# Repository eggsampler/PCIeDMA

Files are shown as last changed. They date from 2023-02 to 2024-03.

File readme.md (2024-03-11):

# PCIeDMA

Open source Artix-7 FPGA designed to be used with [PCILeech](https://github.com/ufrisk/pcileech/).

For schematic/layout/assembly/pcb diagrams, please see the [outputs](outputs/) folder.

## Overview

Initial design was based on a combination of the [LambdaConcept PCIe Screamer Squirrel](https://shop.lambdaconcept.com/home/50-screamer-pcie-squirrel.html) and the [Enigma-X1 LeetDMA](https://enigma-x1.com/store/product/23-leetdma-incl-custom-fw/).

PCIexpress layout is based on [lucanastasio/PCIexpress-KiCad](https://github.com/lucanastasio/PCIexpress-KiCad) PCIexpress_x4_low.

Initially will try to keep the board as a 6-layer PCB using the [JLC3313 6-Layer Impedance Control Stackup](https://cart.jlcpcb.com/impedance), layer stackup plan would be Signal/Ground/Power/Power/Ground/Signal, with the outside signal layers also having a ground pour. PCIe and USB3 SS traces would be impedance matched (and length matched as necessary) on top and bottom layers as coplanar waveguides for each pair.

There are two on-board USB-C ports, one for JTAG debugging/programming of the FPGA/flash, the other as a usb superspeed link for DMA access. The board is also designed such that it can be powered and programmed/tested from the JTAG USB connector, without needing to be plugged into a PCIe slot.

## Progress 

From a high level perspective, the board is largely complete. It does, however, need to be checked before first batch ordered. The following is a rough list of what needs to be reviewed, and any input is welcome from knowledgeable parties.

* [ ] Schematic Review
  * [ ] Part Selection
  * [ ] BOM Check
  * [ ] Connectivity

* [ ] PCB Review
  * [ ] Placement
  * [ ] Footprints
  * [ ] Routing
  * [ ] Impedance

Once board is finalised, the software side needs to be started integrating with PCILeech. Specifically, [PCILeech FPGA](https://github.com/ufrisk/pcileech-fpga)

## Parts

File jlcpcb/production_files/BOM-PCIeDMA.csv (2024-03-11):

Comment | Designator | Footprint | LCSC
EA3059 | U12 | QFN-24-1EP_4x4mm_P0.5mm_EP2.6x2.6mm | C111586
1k | R24,R25,R26,R27,R29,R30,R31,R32,R33,R34,R35,R36,R37,R38,R39,R40,R64,R66,R67,R71,R9 | R_0402_1005Metric | C11702
USB_C_Receptacle | J4 | USB_C_Receptacle_Molex_105450-0101 | C134092
110k | R43 | R_0402_1005Metric | C138065
15 | R1,R4 | R_0402_1005Metric | C144049
100u | C72 | C_1206_3216Metric | C15008
AO3401A | Q2,Q3,Q5 | SOT-23 | C15127
XC7A35T-FGG484 | U8 | Xilinx_FGG484 | C1521727
0.1u | C101,C119,C120,C121,C122,C124,C126,C127,C128,C14,C21,C24,C26,C29,C31,C32,C33,C34,C35,C36,C37,C38,C39,C40,C41,C42,C44,C45,C48,C49,C88,C89,C9,C91 | C_0402_1005Metric | C1525
220p | C106,C107,C108,C109 | C_0402_1005Metric | C1530
22n | C114,C115,C92,C97 | C_0402_1005Metric | C1532
FT601Q | U7 | QFN-76-1EP_9x9mm_P0.4mm_EP5.81x6.31mm | C1550513
20p | C27,C28 | C_0402_1005Metric | C1554
22p | C93,C98 | C_0402_1005Metric | C1555
HD3SS3220 | U6 | HD3SS3220 | C165155
USB_C_Receptacle_USB2.0 | J2 | USB_C_Receptacle_HRO_TYPE-C-31-M-12 | C165948
0.22u | C1,C10,C11,C12,C13,C15,C16,C17,C18,C2,C3,C4,C5,C6,C7,C8 | C_0402_1005Metric | C16772
TBD | FB1,FB2,FB3 | L_0805_2012Metric | C16903
SW_SPDT | SW5 | ST-0-102-C03-N003-RS | C1788489
4.7u | C123,C125,C130,C131,C43,C46,C47,C51,C52,C59,C60,C66,C67,C75,C76,C78,C79 | C_0603_1608Metric | C19666
MMBT3904 | Q4 | SOT-23 | C20526
ACT | D1,D2,D3,D4,D5,D6 | LED_0603_1608Metric | C2290
USER1 | SW1,SW2,SW3,SW4 | SW_SPST_B3U-1000P | C231329
900k | R19 | R_0805_2012Metric | C247071
100 | R10,R11,R12,R14,R15,R28,R68 | R_0402_1005Metric | C25076
100k | R45,R46,R47,R48,R51,R52,R54,R56,R57,R59,R60,R61,R62,R65 | R_0402_1005Metric | C25741
10k | R21,R22,R41,R42,R50,R63 | R_0402_1005Metric | C25744
50k | R49,R53,R55 | R_0402_1005Metric | C25755
15k | R44 | R_0402_1005Metric | C25756
200k | R20,R58 | R_0402_1005Metric | C25764
4.7k | R69,R70 | R_0402_1005Metric | C25900
5.1k | R13,R16,R17,R18,R2,R3,R5,R6,R7,R8 | R_0402_1005Metric | C25905
8MHz | Y1 | Crystal_SMD_3225-4Pin_3.2x2.5mm | C2682775
47n | C116,C118 | C_0402_1005Metric | C272875
MT47H128M8SH-25E IT_M | U13 | FBGA-60_L10.0-W8.0-P0.80-TL_MICRON_MT47HXXX | C2839094
Conn_01x10 | J3 | PinHeader_1x10_P1.27mm_Vertical | C2938404
100MHz | X1,X2 | Crystal_SMD_3225-4Pin_3.2x2.5mm | C2962756
30MHz | Y2 | Crystal_SMD_3225-4Pin_3.2x2.5mm | C362343
A6H-4101 | SW6 | SW_DIP_SPSTx04_Slide_Omron_A6H-4101_W6.15mm_P1.27mm | C397291
1.6k | R23 | R_0402_1005Metric | C413085
22u | C100,C110,C111,C112,C113,C19,C22,C90,C94,C95,C96,C99 | C_0805_2012Metric | C45783
0.47u | C132,C133,C134,C135,C53,C54,C55,C56,C61,C62,C63,C64,C68,C69,C70,C71,C77,C80,C81,C82,C83,C84,C85,C86,C87 | C_0402_1005Metric | C47339
CH347T | U2 | TSSOP-20_4.4x6.5mm_P0.65mm | C5122332
1.5u | L3,L4,L5,L6 | L_Abracon_ASPI-3012S | C528005
TPD4EUSB30 | U1,U3,U4,U5 | USON-10_2.5x1.0mm_P0.5mm | C558427
IS25WP256D-xL | U9 | WSON-8-1EP_8x6mm_P1.27mm_EP3.4x4.3mm | C77819
4.7uH | L1,L2 | L_Vishay_IHLP-2020 | C844990
2N7002 | Q1 | SOT-23 | C8545
MT2492 | U10,U11 | SOT-23-6 | C89358
47u | C129,C50,C57,C58,C65,C73,C74 | C_1206_3216Metric | C96123
10u | C102,C103,C104,C105,C117,C20,C23,C25,C30 | C_0603_1608Metric | C96446

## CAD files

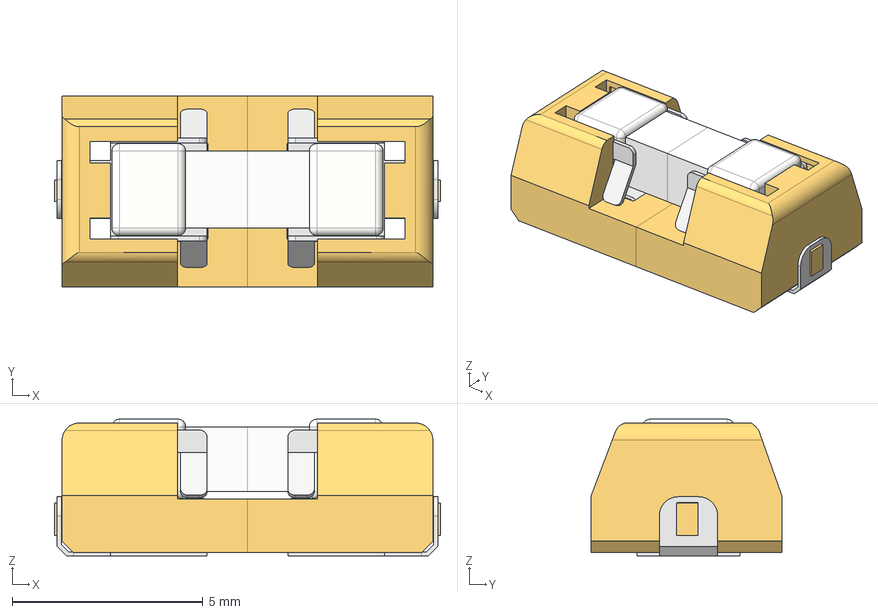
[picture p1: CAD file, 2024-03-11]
3d/Littelfuse 0154.500DRT without value v1.step
10.1 x 5.00 x 3.59 mm
Komponente1
Komponente2
Komponente3
Komponente4

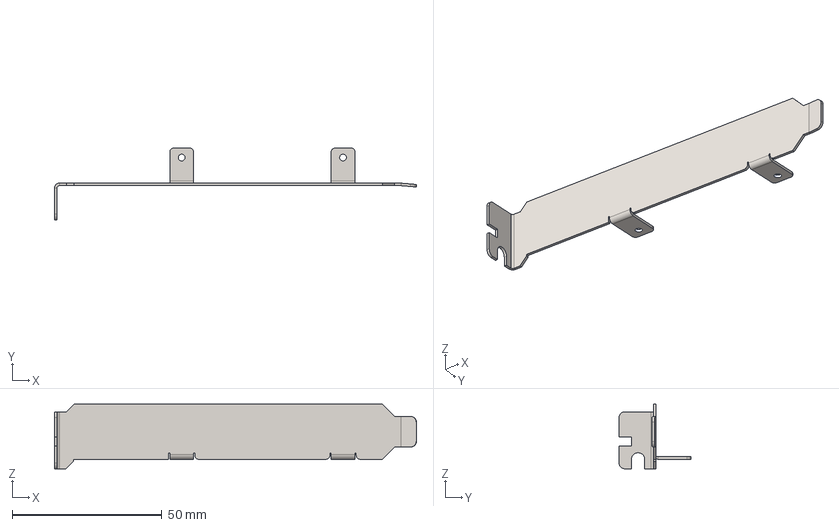
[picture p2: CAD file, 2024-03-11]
3d/PCIexpress_bracket_adapter.step
120.9 x 24.0 x 21.6 mm

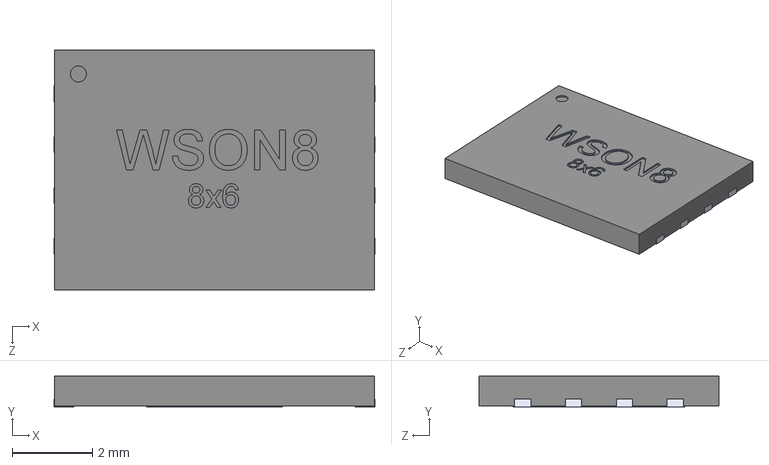
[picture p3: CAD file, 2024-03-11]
3d/WSON8-8x6.STEP
8.02 x 0.77 x 6.00 mm

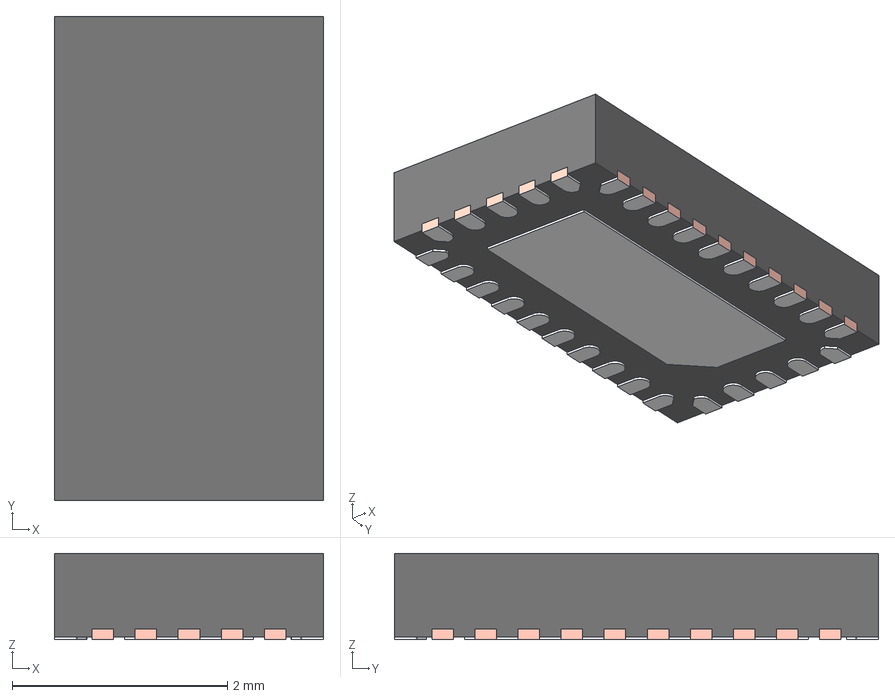
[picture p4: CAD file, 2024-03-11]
3d/RNH0030A.stp
2.50 x 4.50 x 0.8 mm
BODY-QFN
FRAME-RNH0030A
PIN1-ID

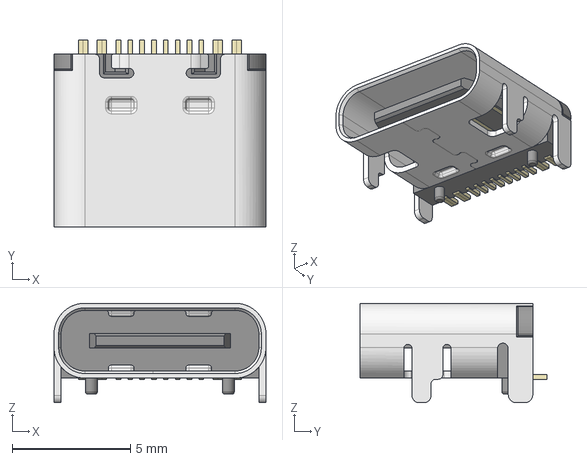
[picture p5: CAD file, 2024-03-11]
3d/HRO_TYPE-C-31-M-12.step
8.95 x 7.90 x 4.20 mm

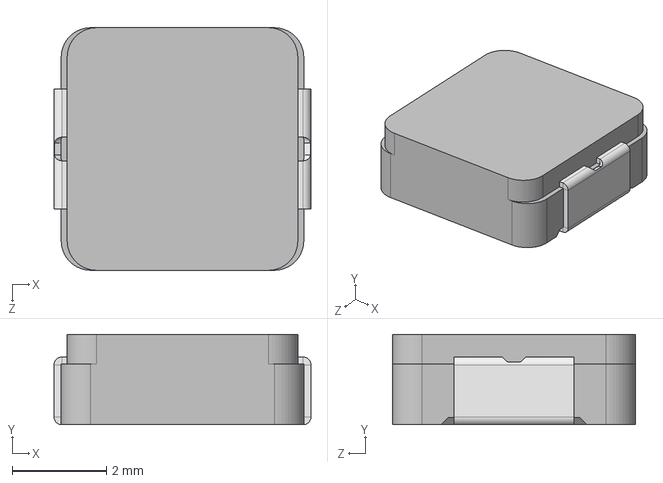
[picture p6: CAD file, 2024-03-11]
3d/IHLP2020BZ.STEP
5.45 x 1.92 x 5.15 mm

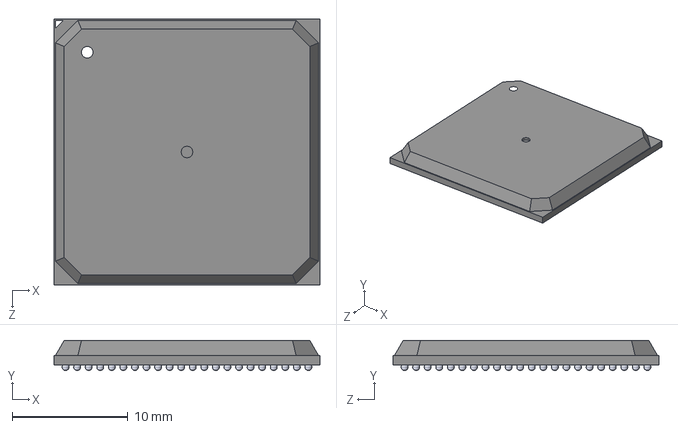
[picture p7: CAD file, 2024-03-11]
3d/XC7A35T-3FGG484E.STEP
23.0 x 2.60 x 23.0 mm

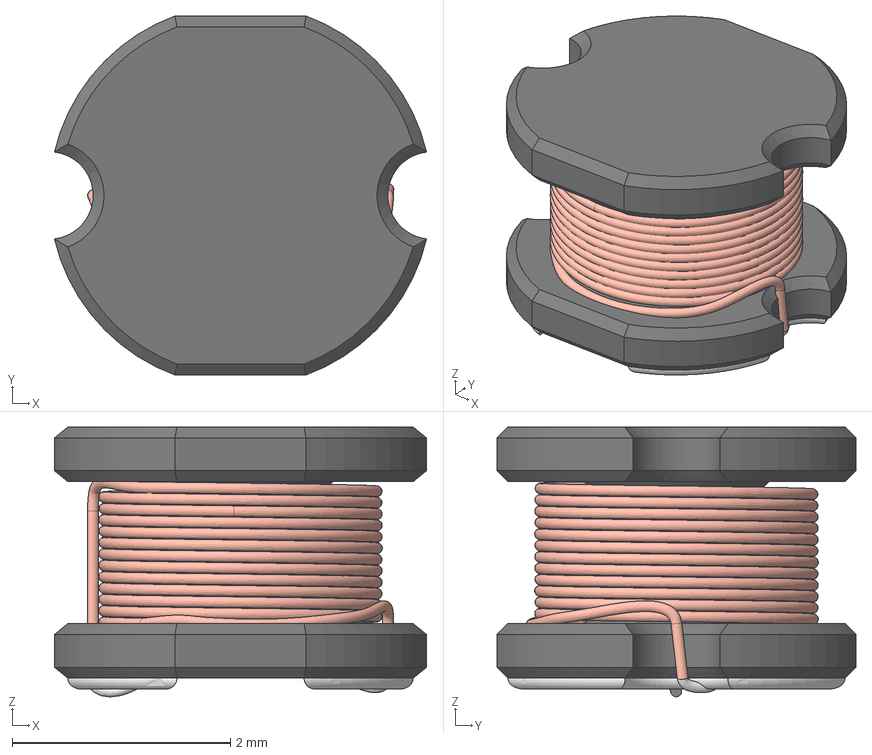
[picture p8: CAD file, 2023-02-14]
3d/Inductor_CD32.STEP
3.41 x 3.29 x 2.47 mm

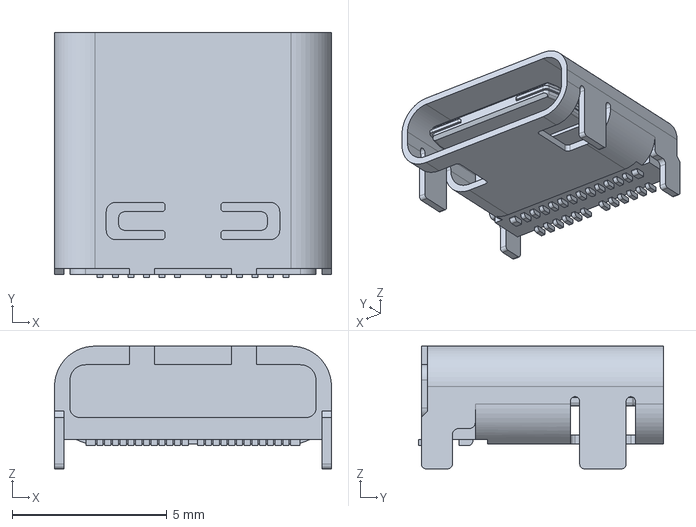
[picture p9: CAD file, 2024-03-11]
3d/1054500101.stp
8.94 x 7.90 x 3.96 mm

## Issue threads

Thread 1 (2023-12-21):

please reply

cht870422, 2023-12-21:
Has your engineering project undergone sample testing?

eggsampler, 2023-12-21:
No. Project needs to be reviewed and have some changes made before production.

cht870422, 2023-12-22:
Less appearance, less drilling, less resistance welding,

cht870422, 2023-12-23:
You can conduct a final error check on your project and submit an update. I can help you make samples and conduct testing If you have any needs, I can also send you a sample card by mail I live in China and manufacturing this hardware is very easy and affordable

eggsampler, 2023-12-24:
I might have time to look at this over the Christmas break - what do you want to use it for>

cht870422, 2023-12-24:
Thank you for taking the time to reply and be willing to conduct the final inspection for this project. I have a suggestion that this PCB can be changed from 8 layers to 4 layers. If you use a 4-layer circuit board, the production cost will be reduced. You can leave your mailing address or contact information for online communication. I suggest using WeChat because it supports translation, or you recommend a communication software

Inzilkin, 2024-01-08:
@eggsampler, Hi. I see that the development process has started, any info on plans or timelines?

eggsampler, 2024-01-14:
No solid plans or timelines, unless you have FPGA design experience.

GRRENY, 2024-01-15:
> 感谢您抽出宝贵时间回复并愿意对本项目进行最终检查。我有一个建议，这个PCB可以从8层改成4层。如果使用4层电路板，生产成本会降低。您可以留下您的邮寄地址或联系信息以进行在线交流。我建议使用微信，因为它支持翻译，或者您推荐使用通信软件

Hello, I also live in China. May I ask which platform is the cheapest to produce samples?

eggsampler, 2024-01-15:
I have no idea if this will even work yet, needs review.

GRRENY, 2024-01-18:
Hello, thank you for the open source of the project. Have you finished reviewing these project materials? If you have reviewed it and it is correct, I am ready to produce a sample of the project. It is recommended that you leave your contact information, I have some questions I hope you can help me solve, thank you very much.

GRRENY, 2024-01-23:
Can you add your contact details? Hope to communicate with you further

eggsampler, 2024-01-23:
No communication required, needs to be reviewed by someone with fpga design experience.

Closed 2024-01-23.

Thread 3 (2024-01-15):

request

GRRENY, 2024-01-15:
Hello, can you share the production materials of other DMA equipment with me? It must be like PCIe Squirrel or Leet DMA, Captain DMA. Thank you very much and look forward to hearing from you。

eggsampler, 2024-01-15:
I have no idea what other cards use.

Closed 2024-01-15.

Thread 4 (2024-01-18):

Ask for help

GRRENY, 2024-01-18:
Hello, thank you for the open source of the project. Have you finished reviewing these project materials? If you have reviewed it and it is correct, I am ready to produce a sample of the project. It is recommended that you leave your contact information, I have some questions I hope you can help me solve, thank you very much.

GRRENY, 2024-01-20:
Once you have reviewed the project materials, I will produce a sample and mail it to you immediately.

Closed 2024-01-23.

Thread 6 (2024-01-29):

Amazing work. Part information

Rvnxxx, 2024-01-29:
Hay if at any point you are not too busy finishing DMA board. would you be able to put a list together and if/possible set of links to the chips/parts needed for the DMA board to be assembled in order for it to work? again amazing work <3.

eggsampler, 2024-01-30:
The BOM and placement files are in the output folder.

I do not recommend ordering until more work is done

Closed 2024-01-30.

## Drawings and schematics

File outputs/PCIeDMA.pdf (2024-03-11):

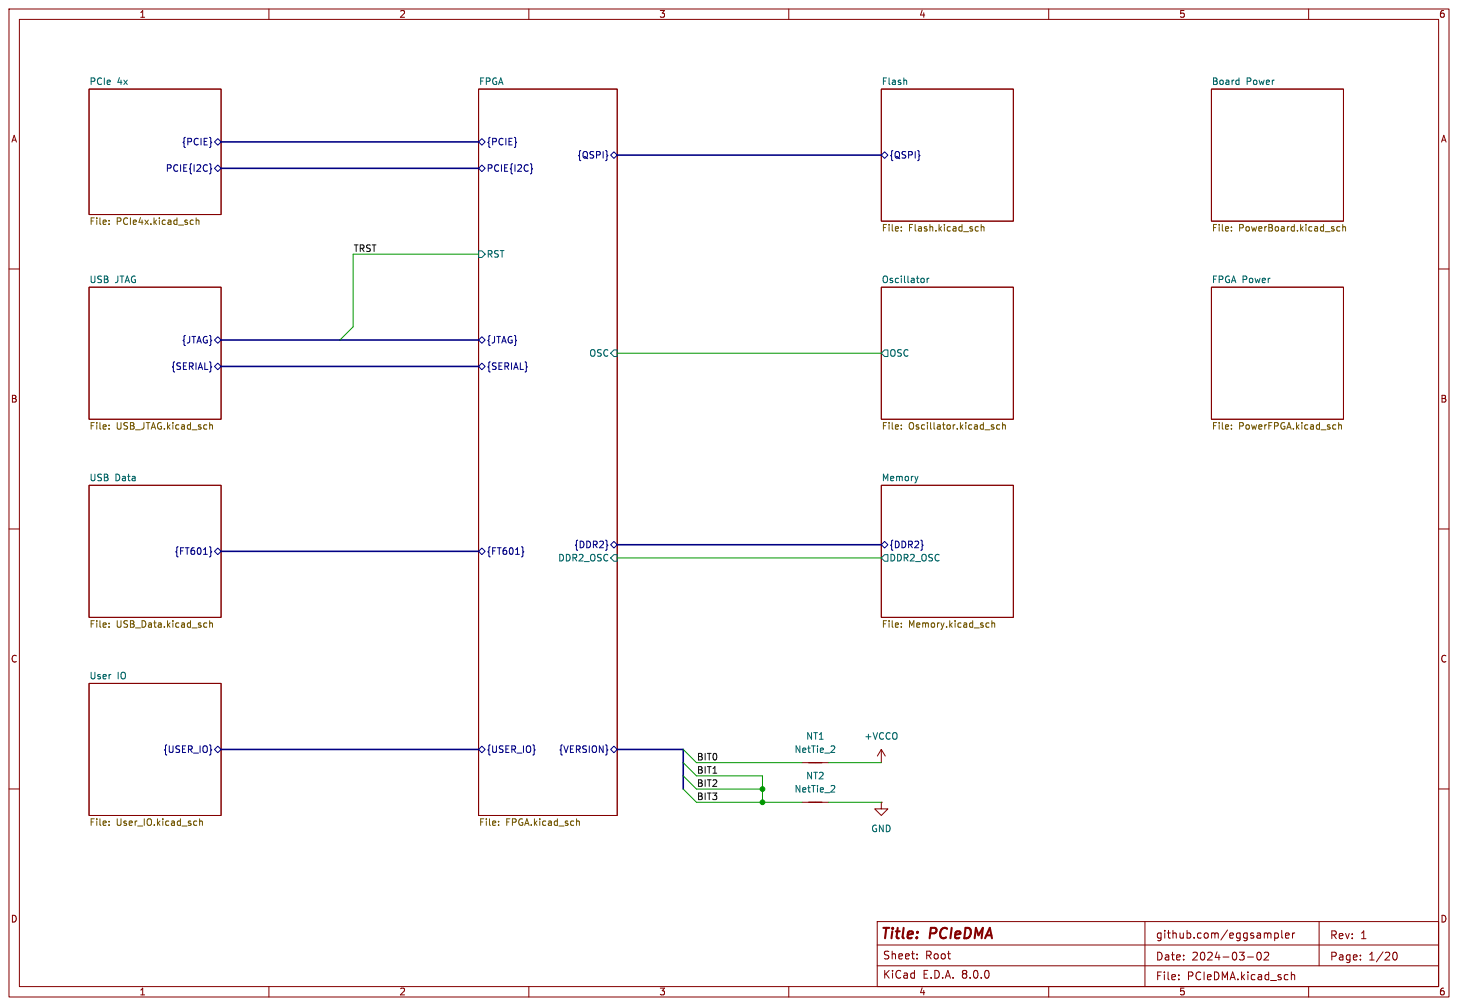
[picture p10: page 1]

{QSPI} Flash File: Flash.kicad_sch OSC Oscillator File: Oscillator.kicad_sch RST

Board Power File: PowerBoard.kicad_sch +VCCO

FPGA Power File: PowerFPGA.kicad_sch

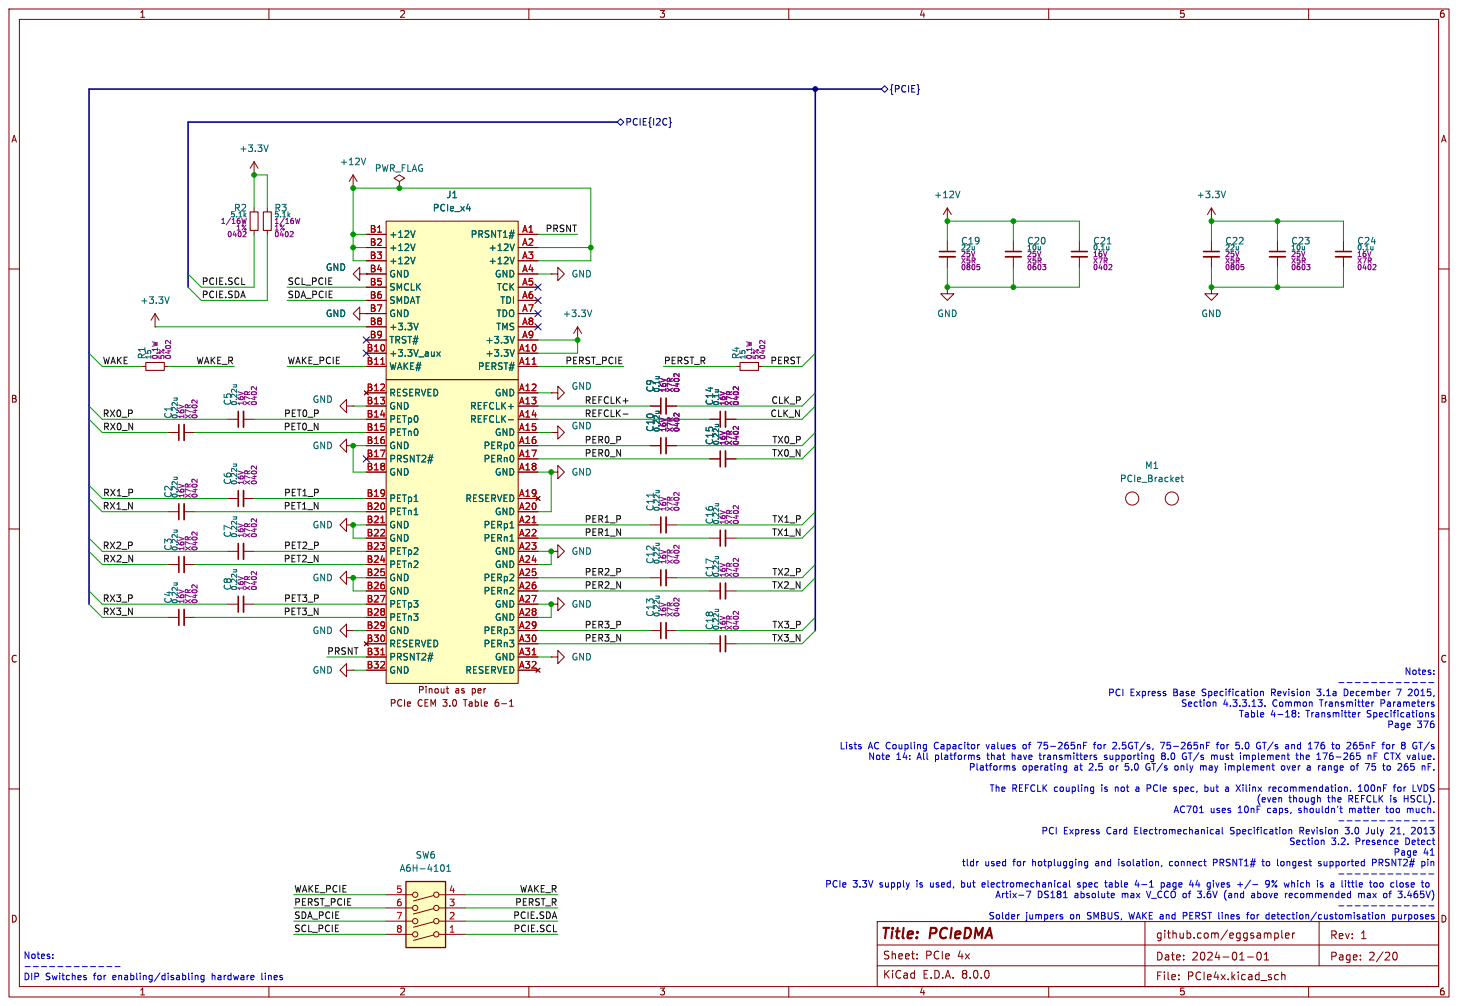
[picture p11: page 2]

PCIE.SCL PCIE.SDA

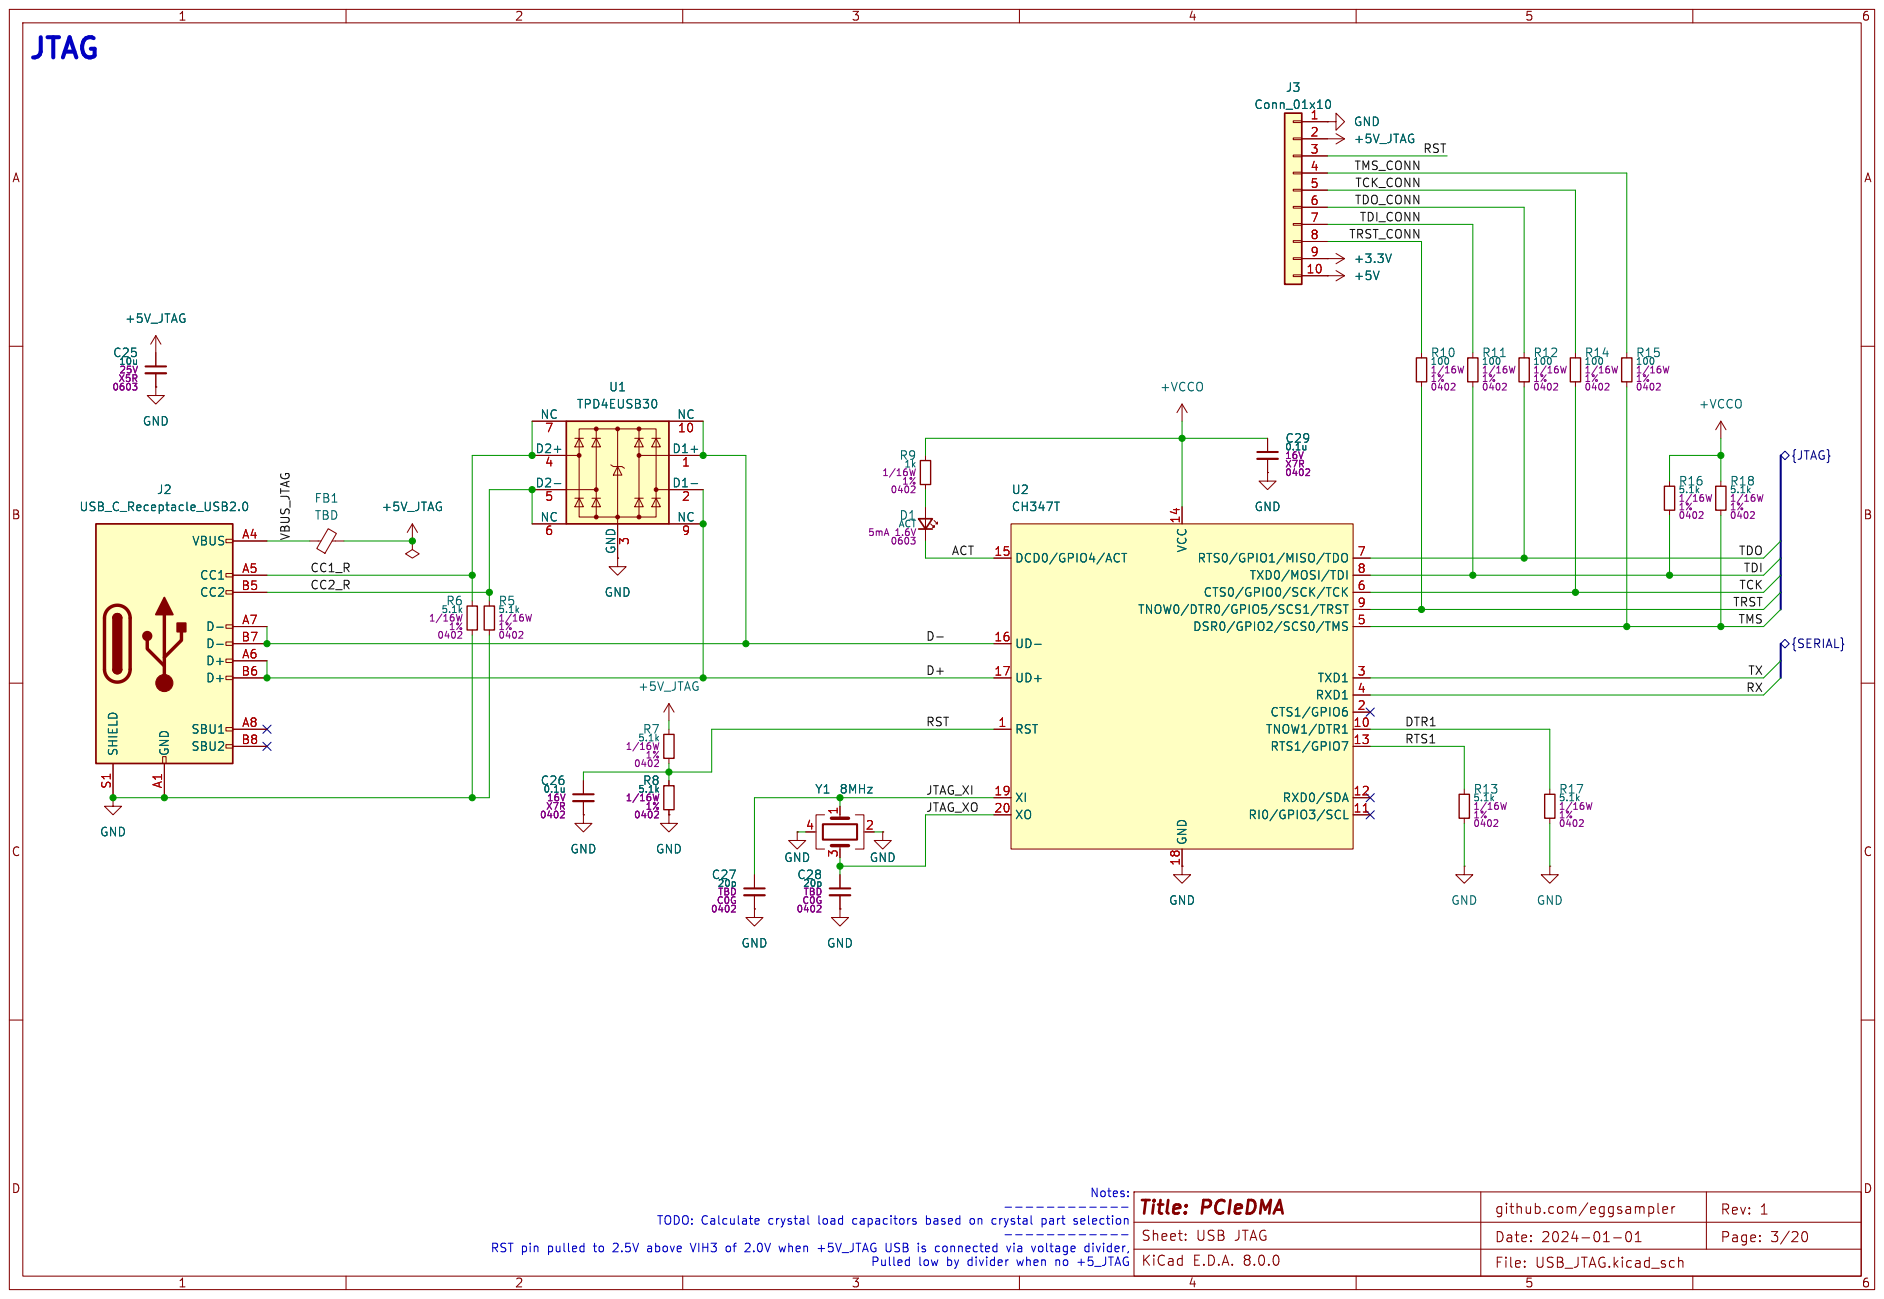
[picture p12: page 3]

github.com/eggsampler GND

File: USB_JTAG.kicad_sch Sheet: USB JTAG

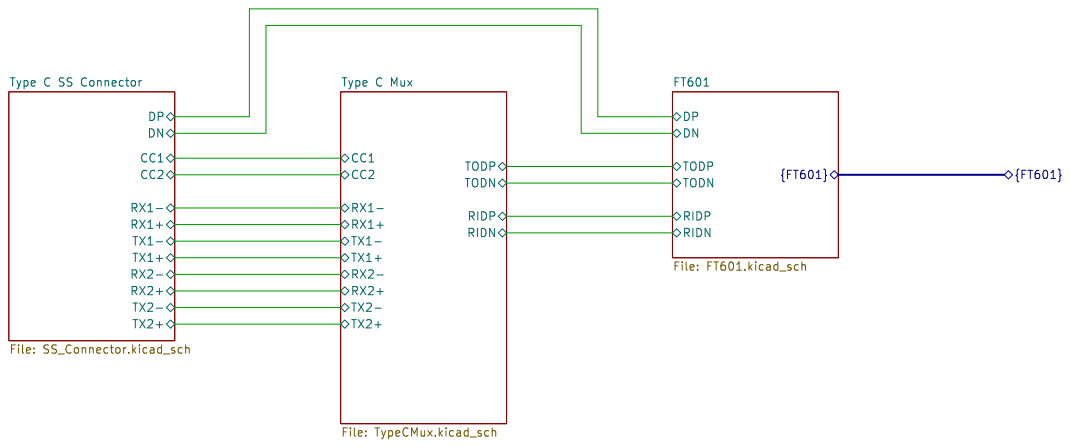
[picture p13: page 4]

TX1+ RX1+ TX1- RX2- TX2- RX2+ RX1- TX2+ CC2 CC1 Type C Mux File: TypeCMux.kicad_sch

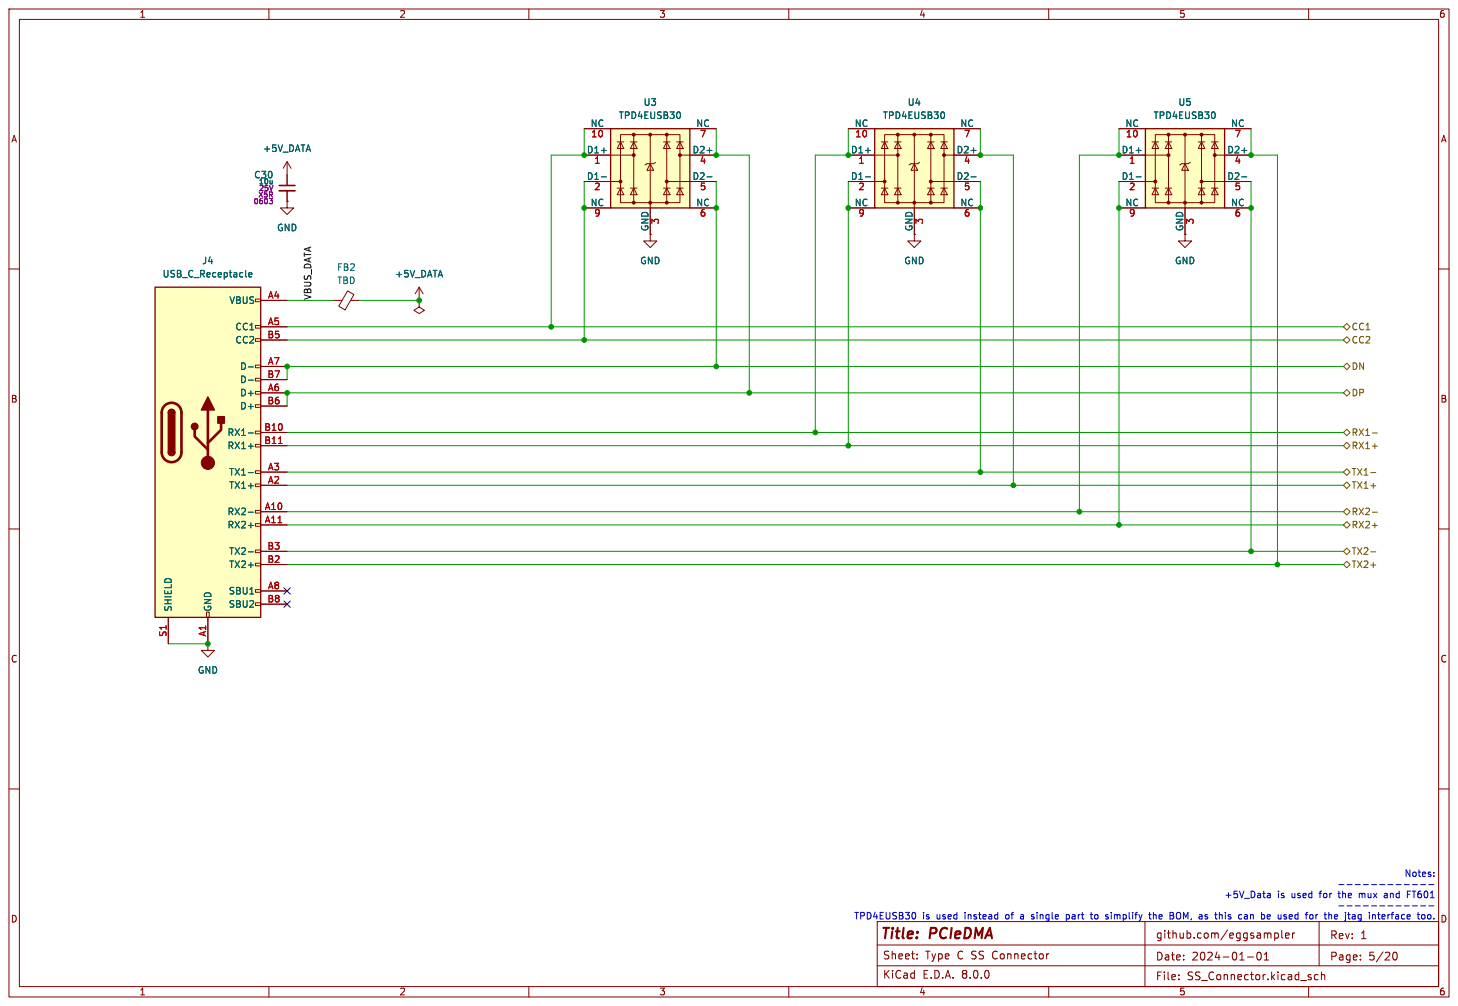
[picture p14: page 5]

Notes: ------------ +5V_Data is used for the mux and FT601

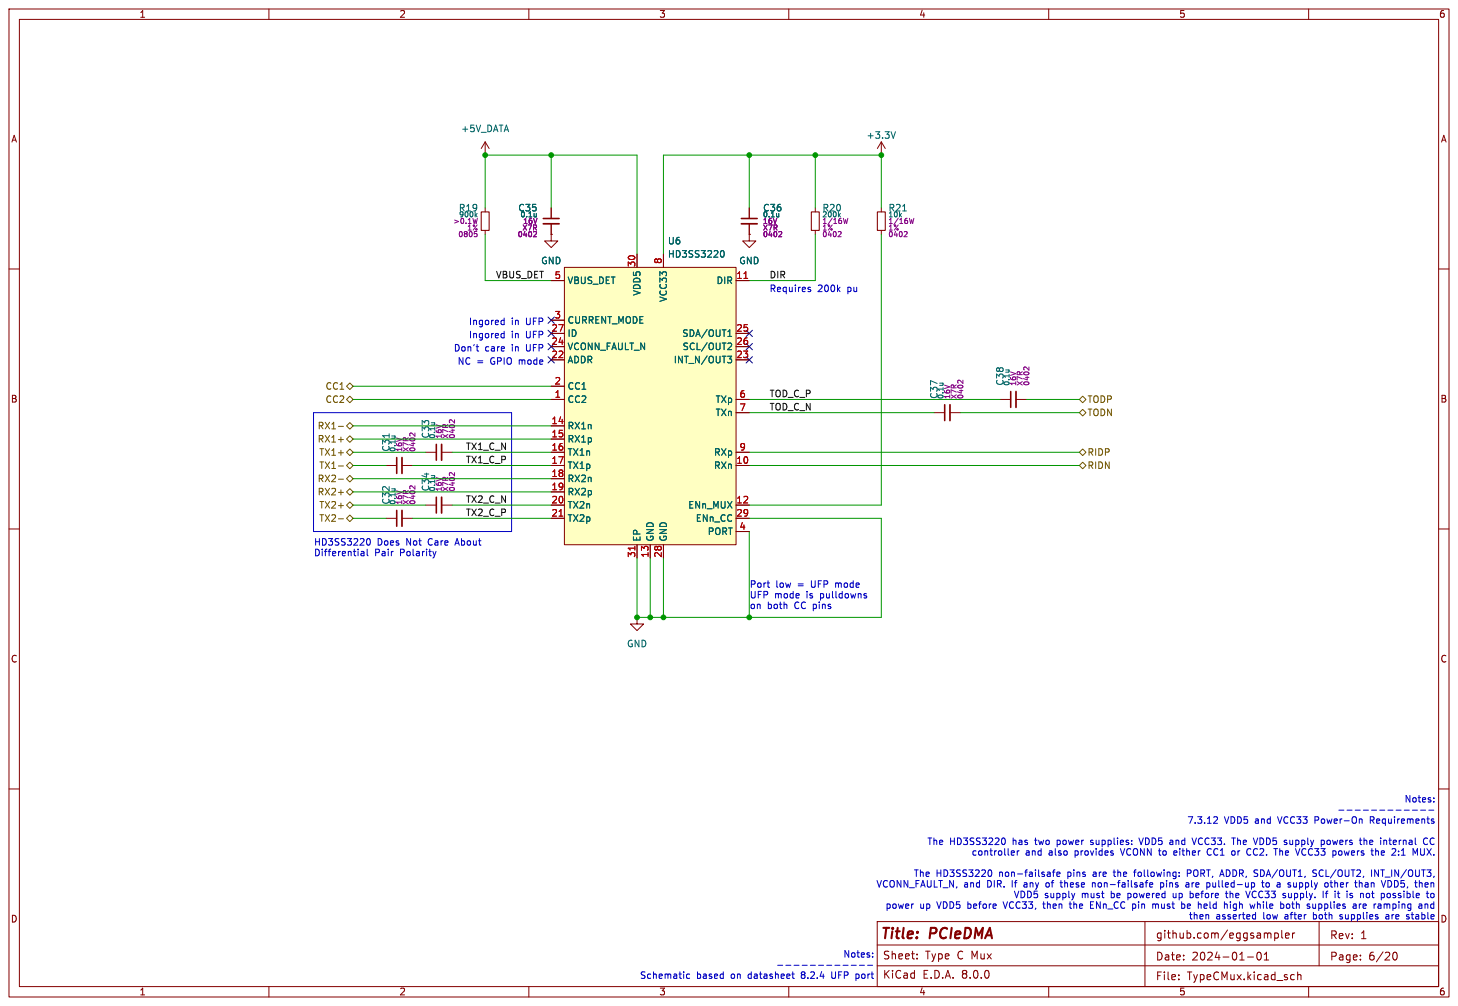
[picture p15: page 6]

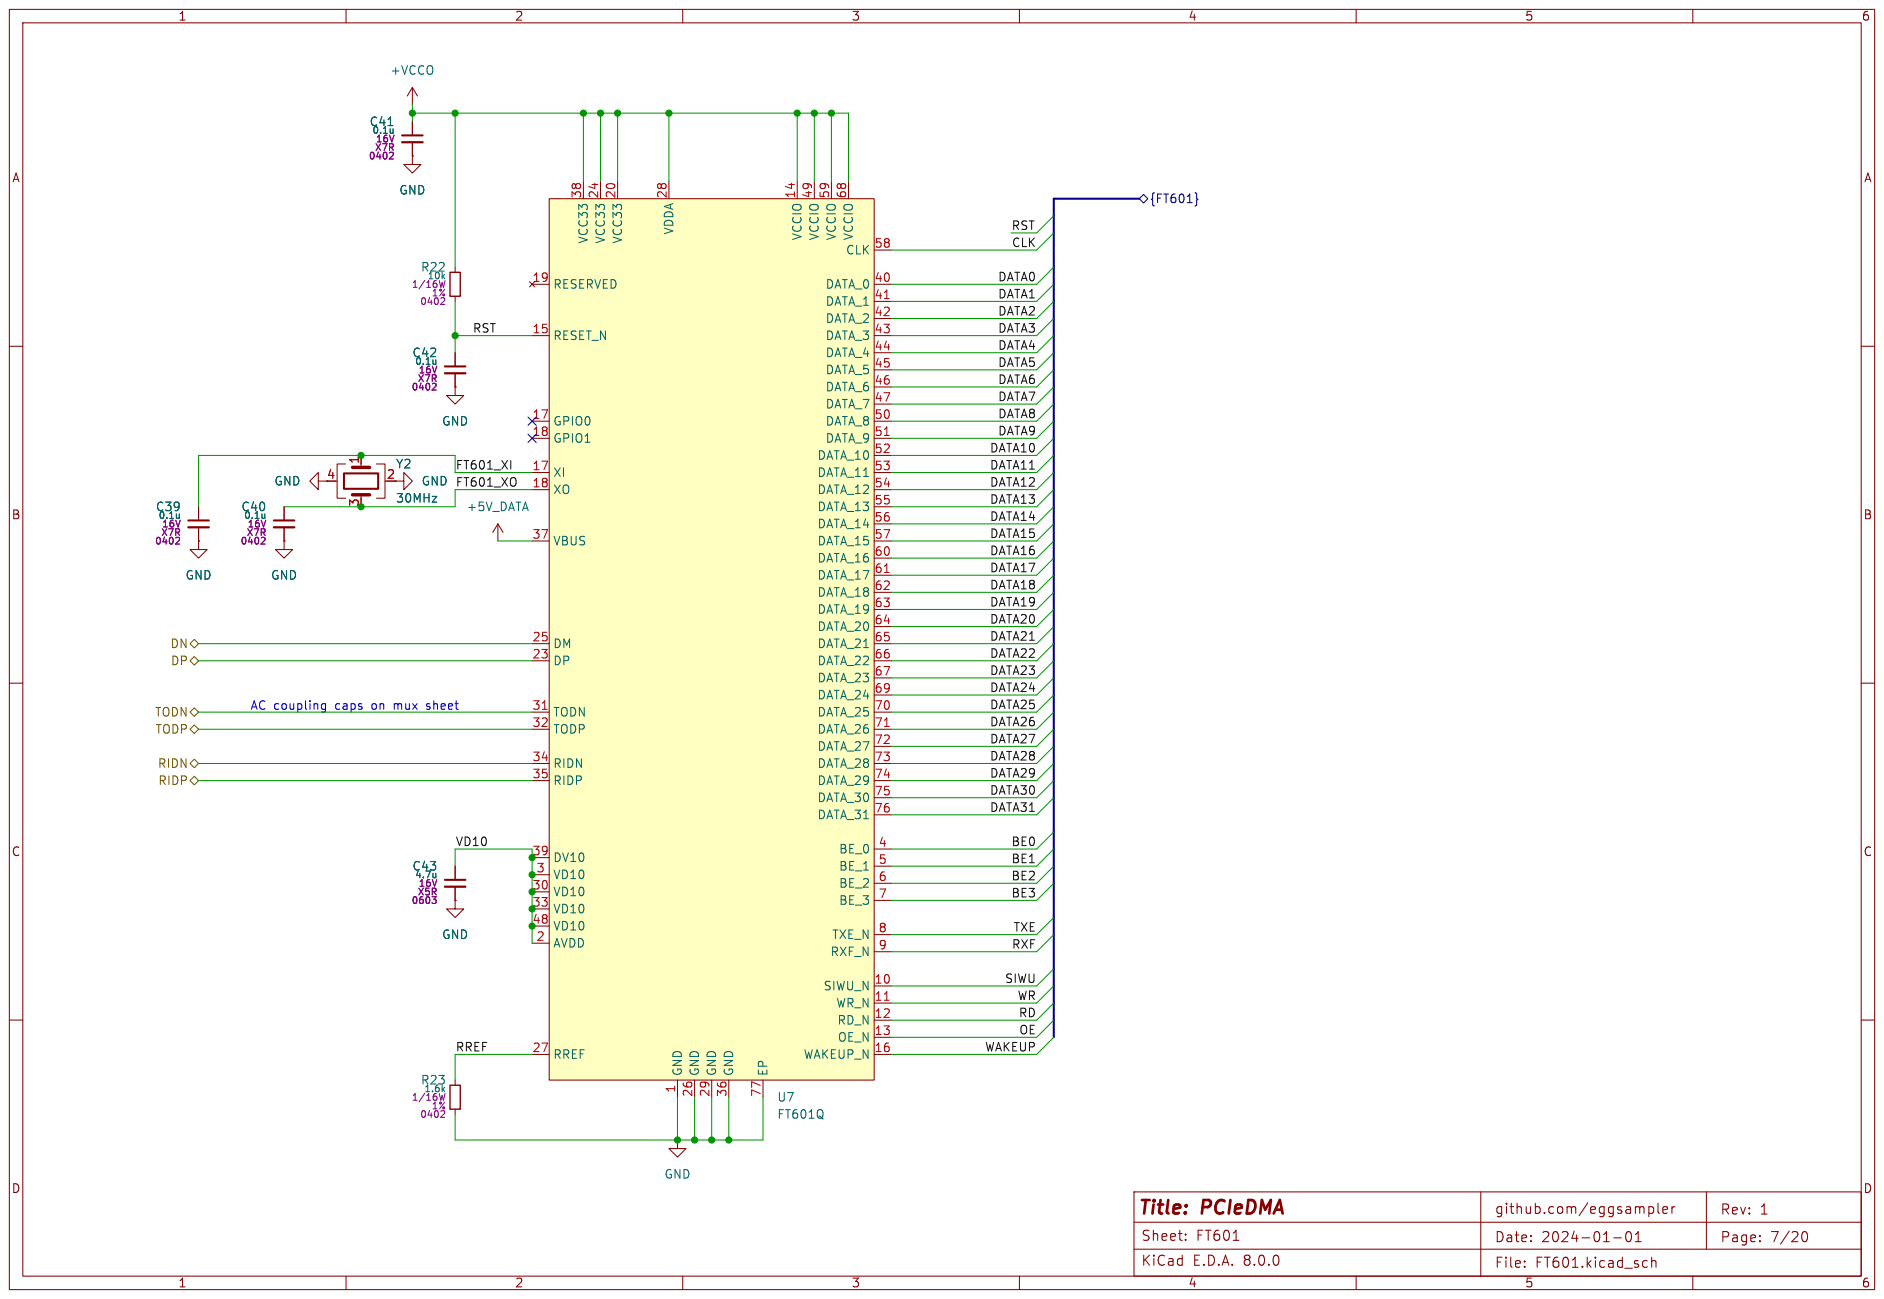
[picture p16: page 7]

github.com/eggsampler GND

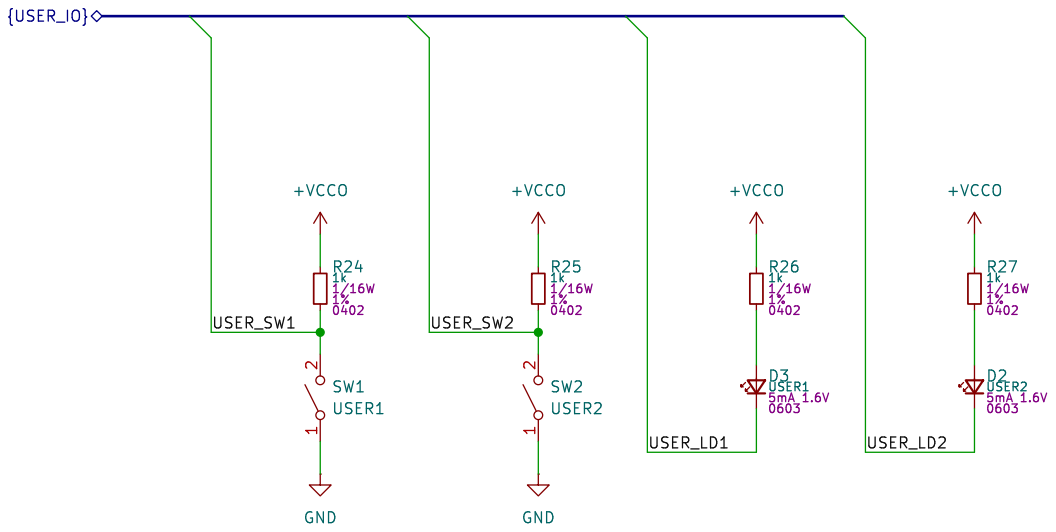
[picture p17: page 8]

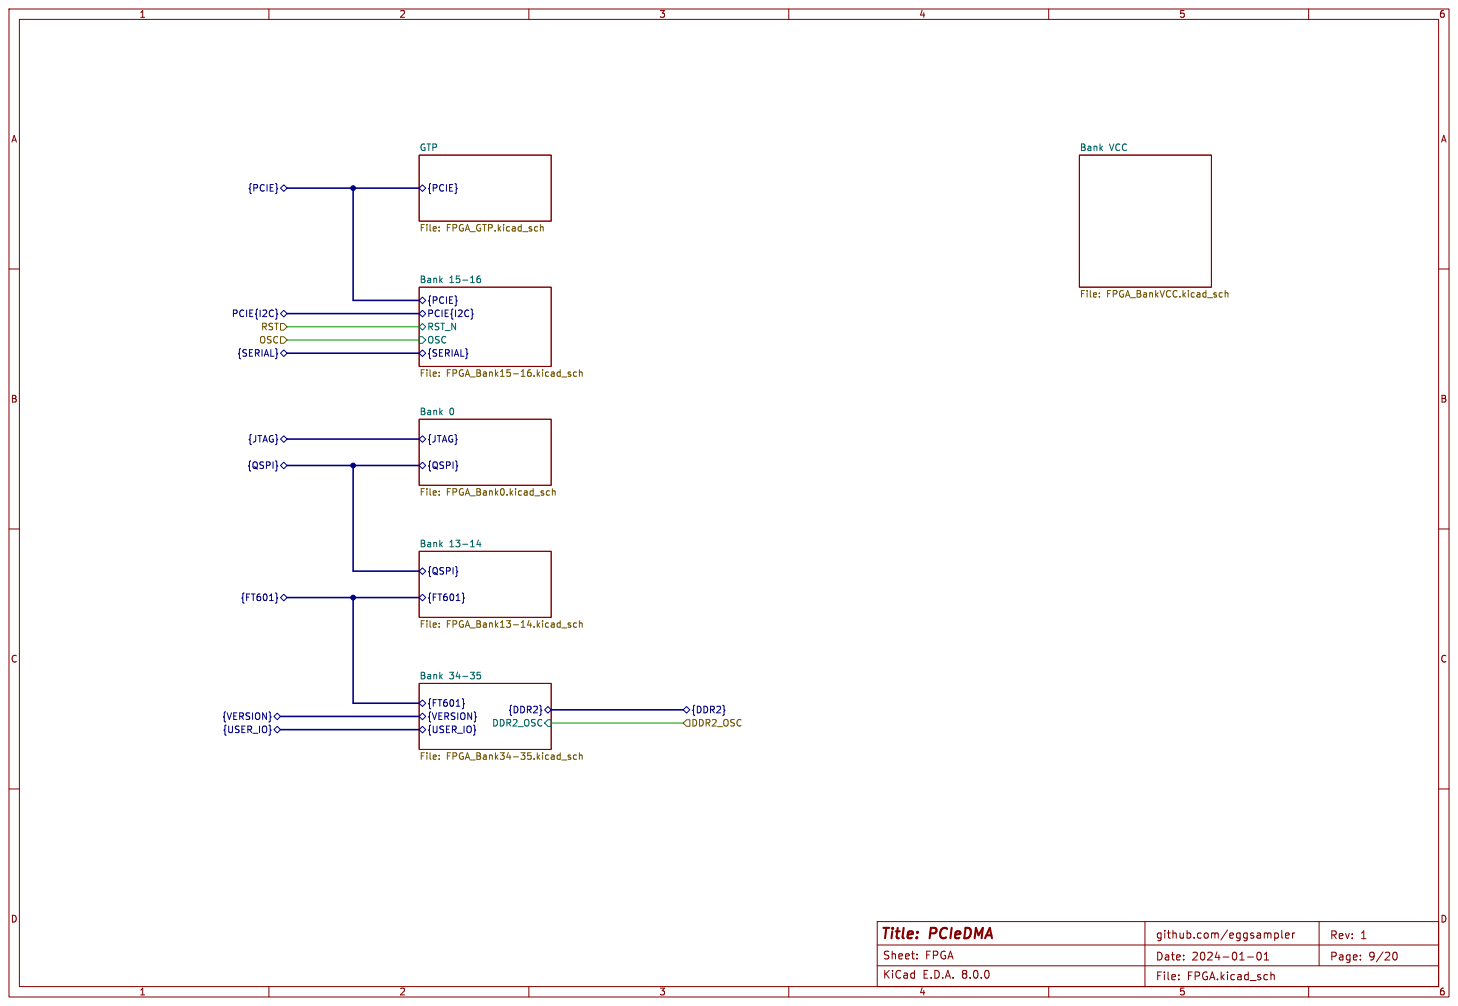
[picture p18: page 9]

{SERIAL} RST PCIE{I2C} OSC

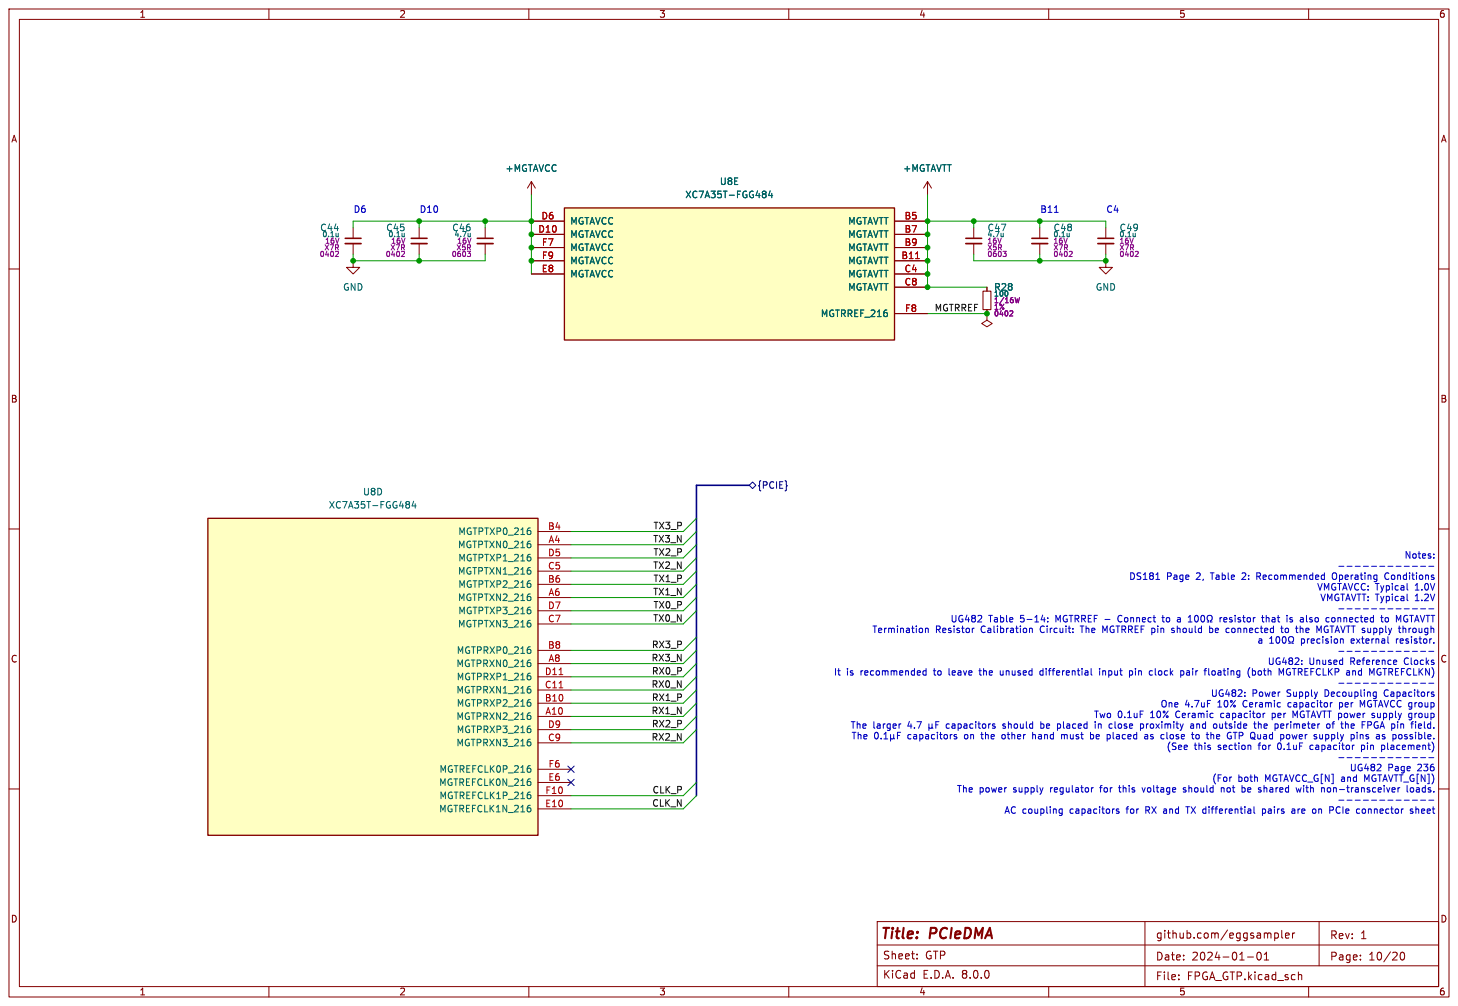
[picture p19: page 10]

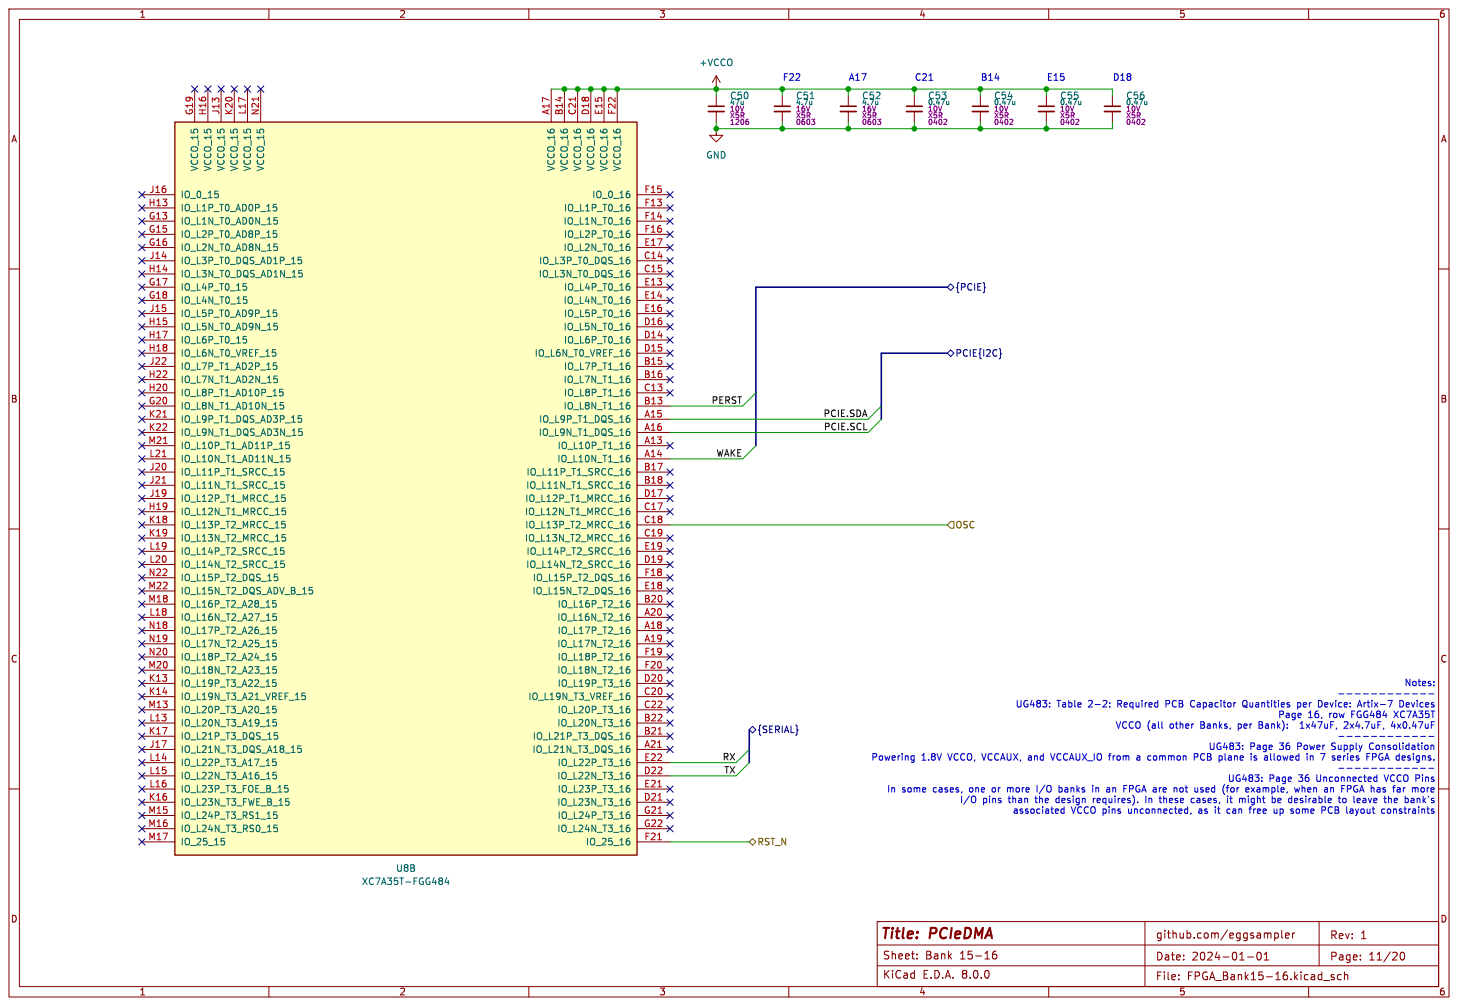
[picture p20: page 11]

In some cases, one or more I/O banks in an FPGA are not used (for example, when an FPGA has far more

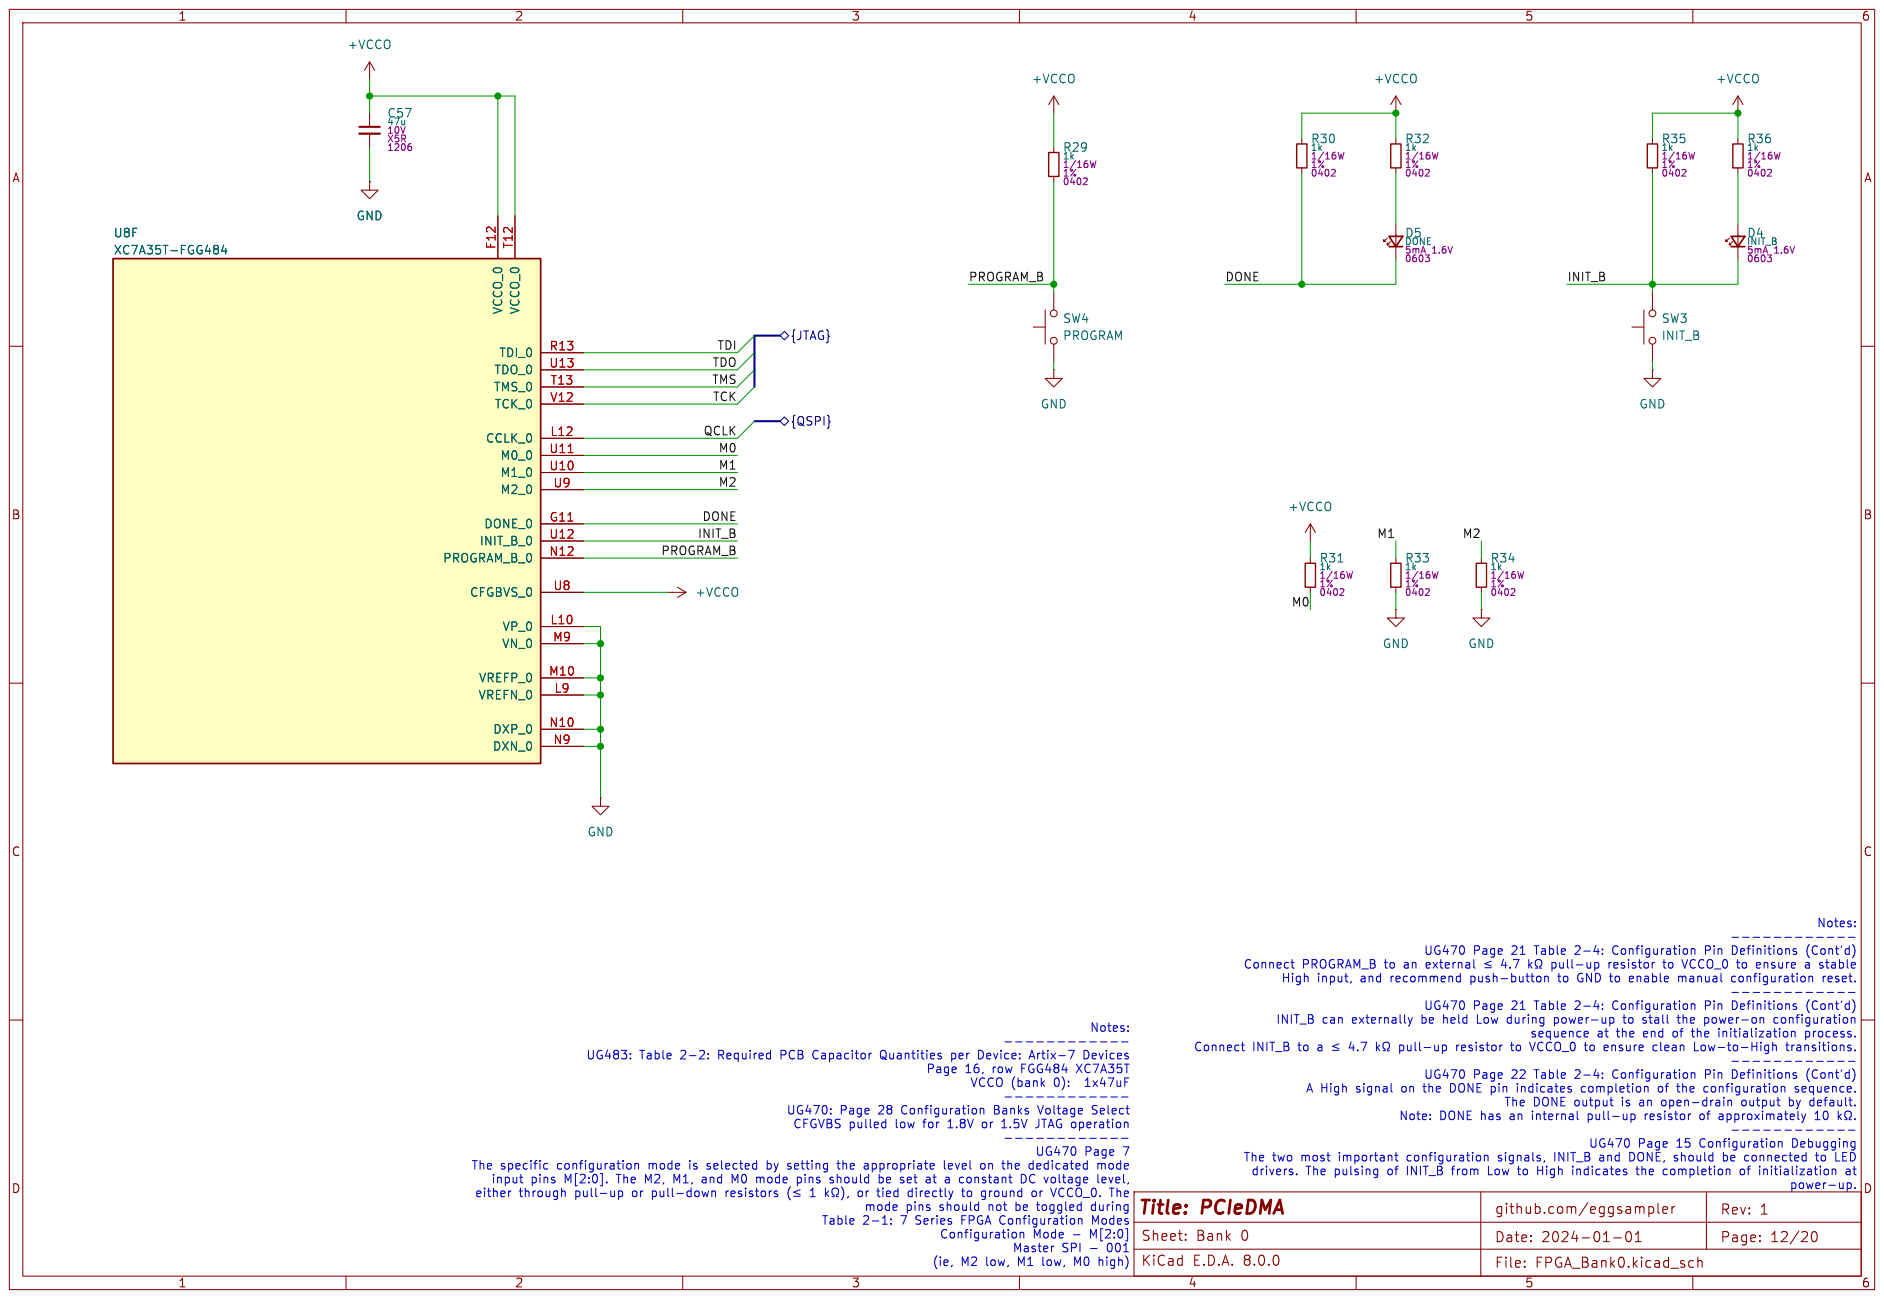
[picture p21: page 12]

(ie, M2 low, M1 low, M0 high)




47uF: < 1210, Ceramic X7R or X5R, 1nH ESL Max, þÿ5m©< ESR < þÿ40m©, > 6.3V
4.7uF: < 0805, Ceramic X7R or X5R, 1nH ESL Max, þÿ5m©< ESR < þÿ20m©, > 6.3V
0.47uF: < 0603, Ceramic X7R or X5R, 0.5nH ESL Max, þÿ5m©< ESR < þÿ20m©, > 6.3V


9.8 POWER-UP AND POWER-DOWN




2 FB 3 EN 4 VIN 5 SW 6 U10 MT2492 C92 22n 50V X7R 0402 GND GND

2 FB 3 EN 4 VIN 5 SW 6 U11 MT2492 GND


Input voltages PCIe: 12V, 3.3V, 3.3V_aux USB: 5V Output voltages VCCO: 3.3V

VCCINT: 1.0V
VCCBRAM: Use VCCINT VCCAUX: 1.8V MGTAVCC: 1.0V MGTAVTT: 1.2V

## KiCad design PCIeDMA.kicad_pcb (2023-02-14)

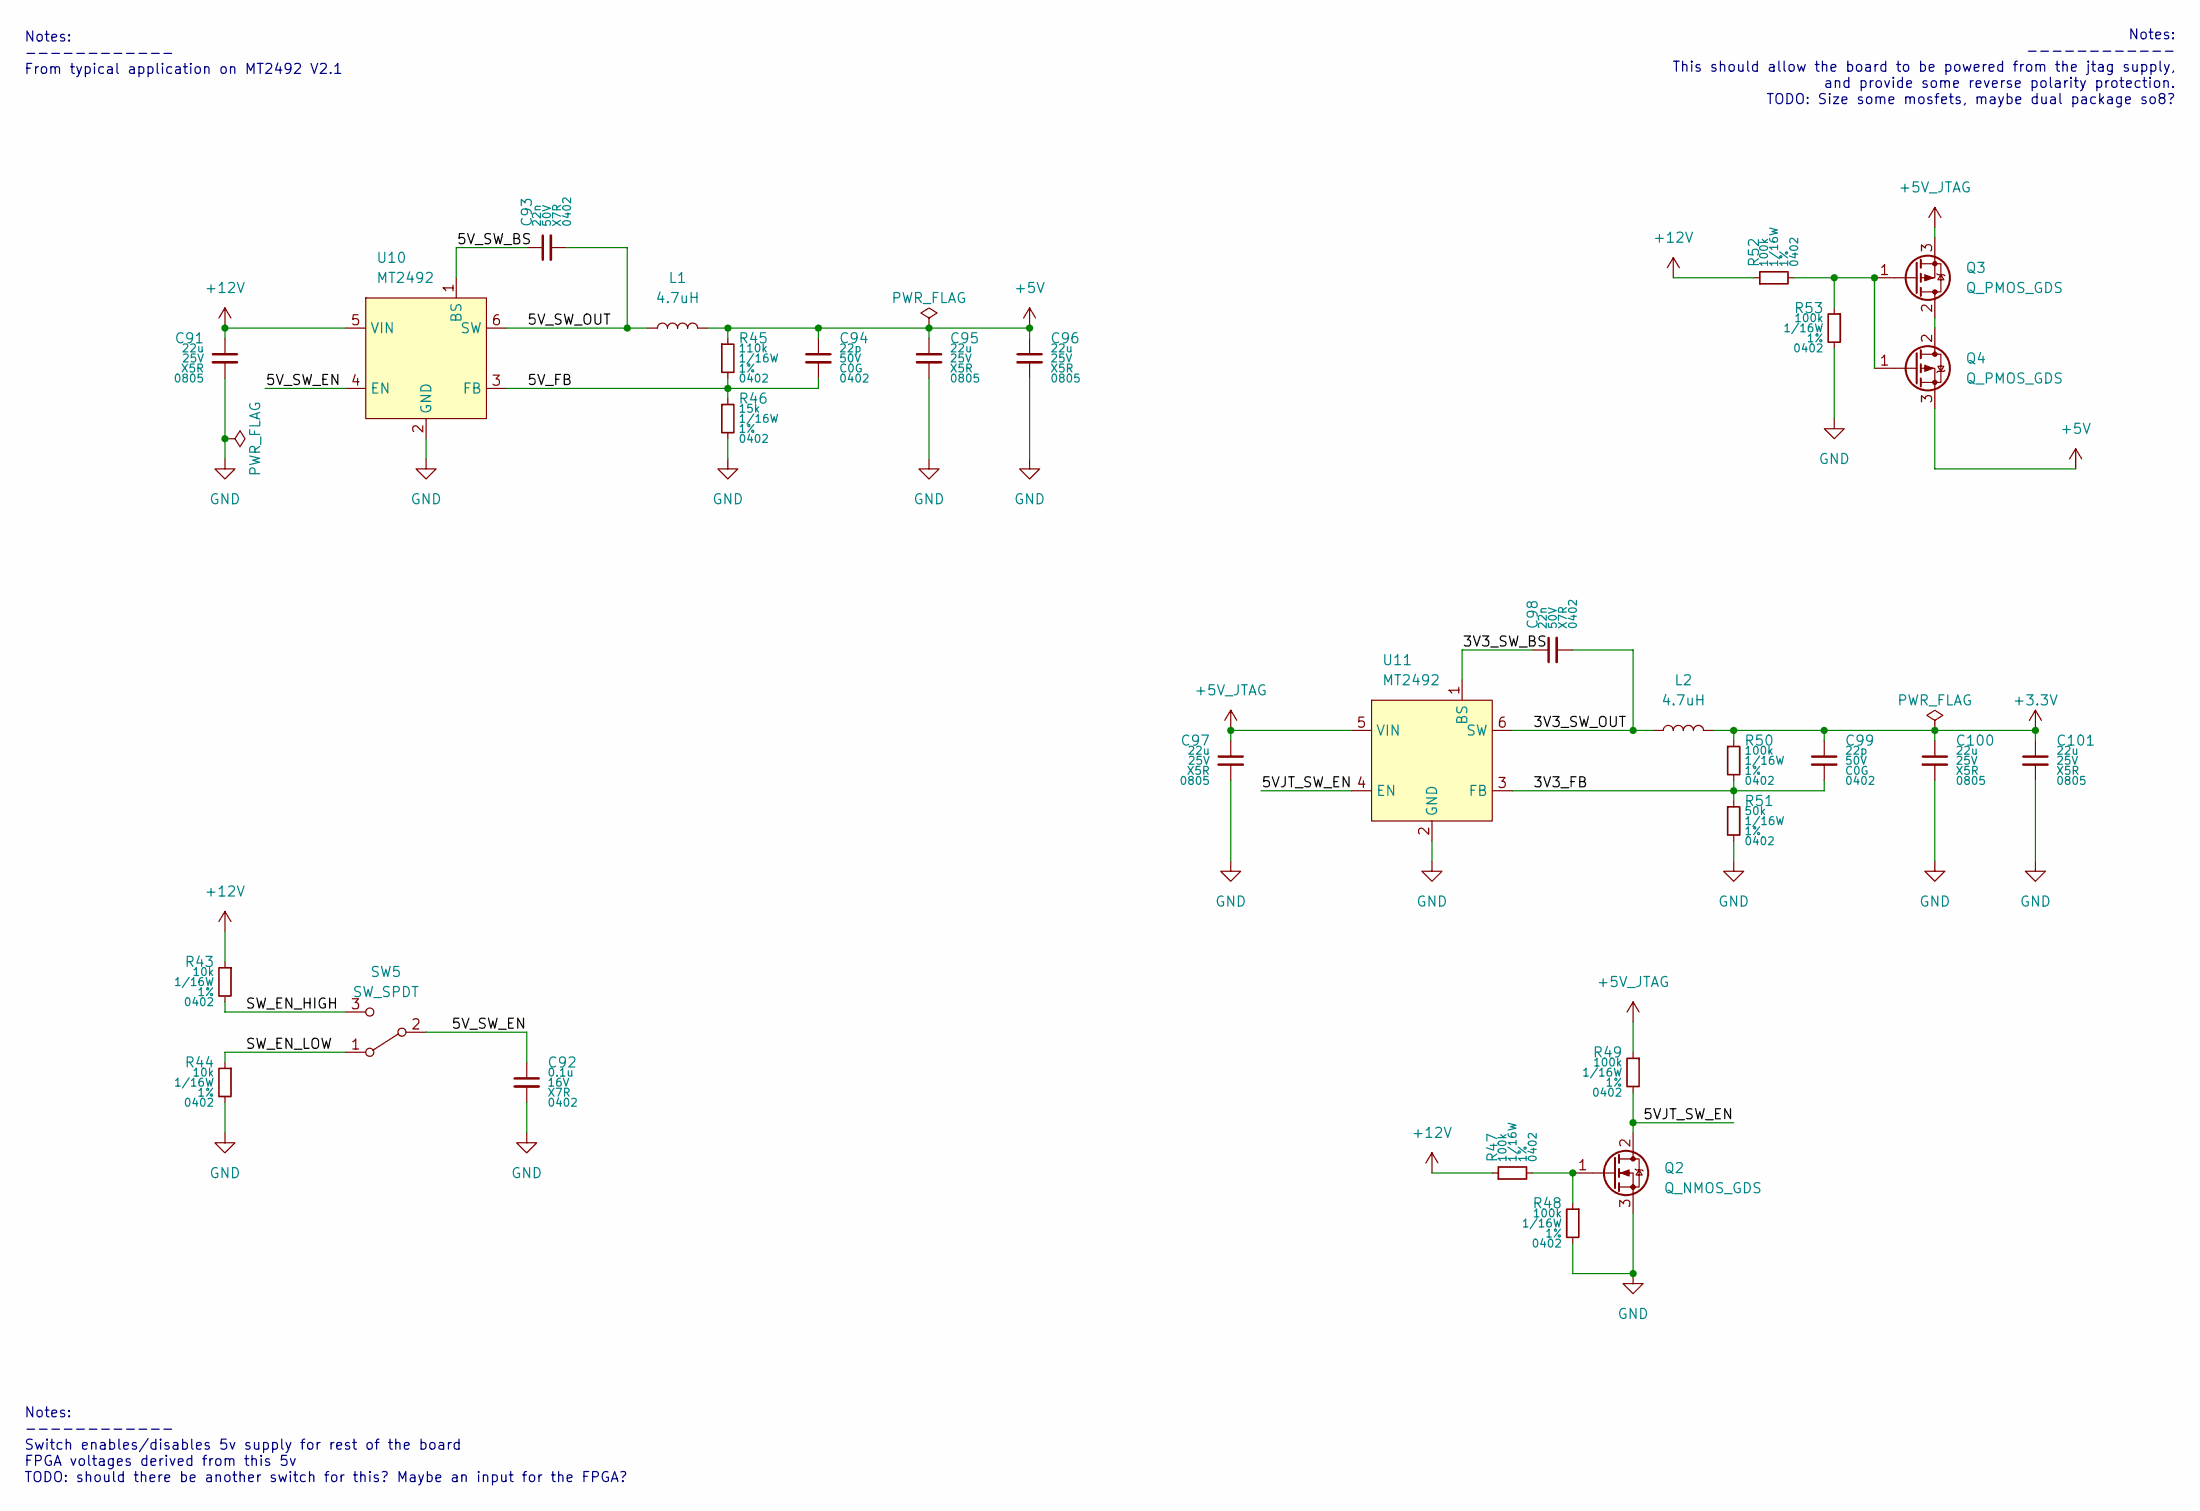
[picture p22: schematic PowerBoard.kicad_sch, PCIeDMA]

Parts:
C91, C95, C96, C97, C100, C101: 22u; C_0805_2012Metric; Rating 25V
C92: 0.1u; C_0402_1005Metric; Rating 16V
C93, C98: 22n; C_0402_1005Metric; Rating 50V
C94, C99: 22p; C_0402_1005Metric; Rating 50V
L1, L2: 4.7uH; L_Vishay_IHLP-2020
Q2: Q_NMOS_GDS; SOT-23
Q3, Q4: Q_PMOS_GDS; SOT-23
R43, R44: 10k; R_0402_1005Metric; Rating 1/16W; Tolerance 1%
R45: 110k; R_0402_1005Metric; Rating 1/16W; Tolerance 1%
R46: 15k; R_0402_1005Metric; Rating 1/16W; Tolerance 1%
R47, R48, R49, R50, R52, R53: 100k; R_0402_1005Metric; Rating 1/16W; Tolerance 1%
R51: 50k; R_0402_1005Metric; Rating 1/16W; Tolerance 1%
SW5: SW_SPDT; ST-0-102-C03-N003-RS
U10, U11: MT2492; SOT-23-6

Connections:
+3.3V: C99.1, C100.1, C101.1, L2.2, R50.1; also elsewhere on the board
+5V: C94.1, C95.1, C96.1, L1.2, Q4.3 (S), R45.1; also elsewhere on the board
+5V_JTAG: C97.1, Q3.3 (S), R49.1, U11.5 (VIN); also elsewhere on the board
+12V: C91.1, R43.1, R47.1, R52.1, U10.5 (VIN); also elsewhere on the board
/Board Power/3V3_FB: C99.2, R50.2, R51.1, U11.3 (FB)
/Board Power/3V3_SW_BS: C98.1, U11.1 (BS)
/Board Power/3V3_SW_OUT: C98.2, L2.1, U11.6 (SW)
/Board Power/5VJT_SW_EN: Q2.2 (D), R49.2, U11.4 (EN)
/Board Power/5V_FB: C94.2, R45.2, R46.1, U10.3 (FB)
/Board Power/5V_SW_BS: C93.1, U10.1 (BS)
/Board Power/5V_SW_EN: C92.1, SW5.2 (B), U10.4 (EN)
/Board Power/5V_SW_OUT: C93.2, L1.1, U10.6 (SW)
/Board Power/SW_EN_HIGH: R43.2, SW5.3 (C)
/Board Power/SW_EN_LOW: R44.1, SW5.1 (A)
GND: C91.2, C92.2, C95.2, C96.2, C97.2, C100.2, C101.2, Q2.3 (S), R44.2, R46.2, R48.2, R51.2, R53.2, U10.2 (GND), U11.2 (GND); also elsewhere on the board
unnamed: Q2.1 (G), R47.2, R48.1
unnamed: Q3.2 (D), Q4.2 (D)
unnamed: Q3.1 (G), Q4.1 (G), R52.2, R53.1

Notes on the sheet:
Notes: ------------ From typical application on MT2492 V2.1
Notes: ------------ Switch enables/disables 5v supply for rest of the board FPGA voltages derived from this 5v TODO: should there be another switch for this? Maybe an input for the FPGA?
Notes: ------------ This should allow the board to be powered from the jtag supply, and provide some reverse polarity protection. TODO: Size some mosfets, maybe dual package so8?

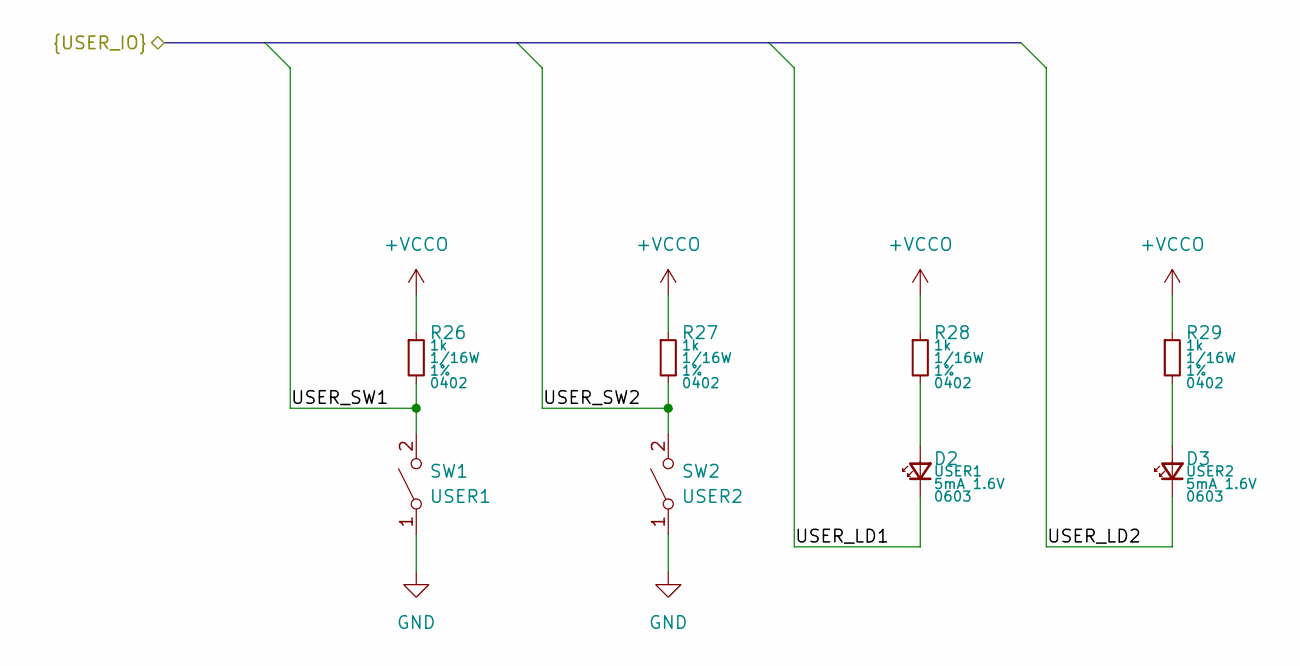
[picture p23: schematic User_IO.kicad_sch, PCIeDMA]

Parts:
D2: USER1; LED_0603_1608Metric; Rating 5mA 1.6V
D3: USER2; LED_0603_1608Metric; Rating 5mA 1.6V
R26, R27, R28, R29: 1k; R_0402_1005Metric; Rating 1/16W; Tolerance 1%
SW1: USER1; SW_SPST_B3U-1000P
SW2: USER2; SW_SPST_B3U-1000P

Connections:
+VCCO: R26.1, R27.1, R28.1, R29.1; also elsewhere on the board
/FPGA/USER_LD1: D2.1 (K); also elsewhere on the board
/FPGA/USER_LD2: D3.1 (K); also elsewhere on the board
/FPGA/USER_SW1: R26.2, SW1.2 (B); also elsewhere on the board
/FPGA/USER_SW2: R27.2, SW2.2 (B); also elsewhere on the board
GND: SW1.1 (A), SW2.1 (A); also elsewhere on the board
unnamed: D2.2 (A), R28.2
unnamed: D3.2 (A), R29.2

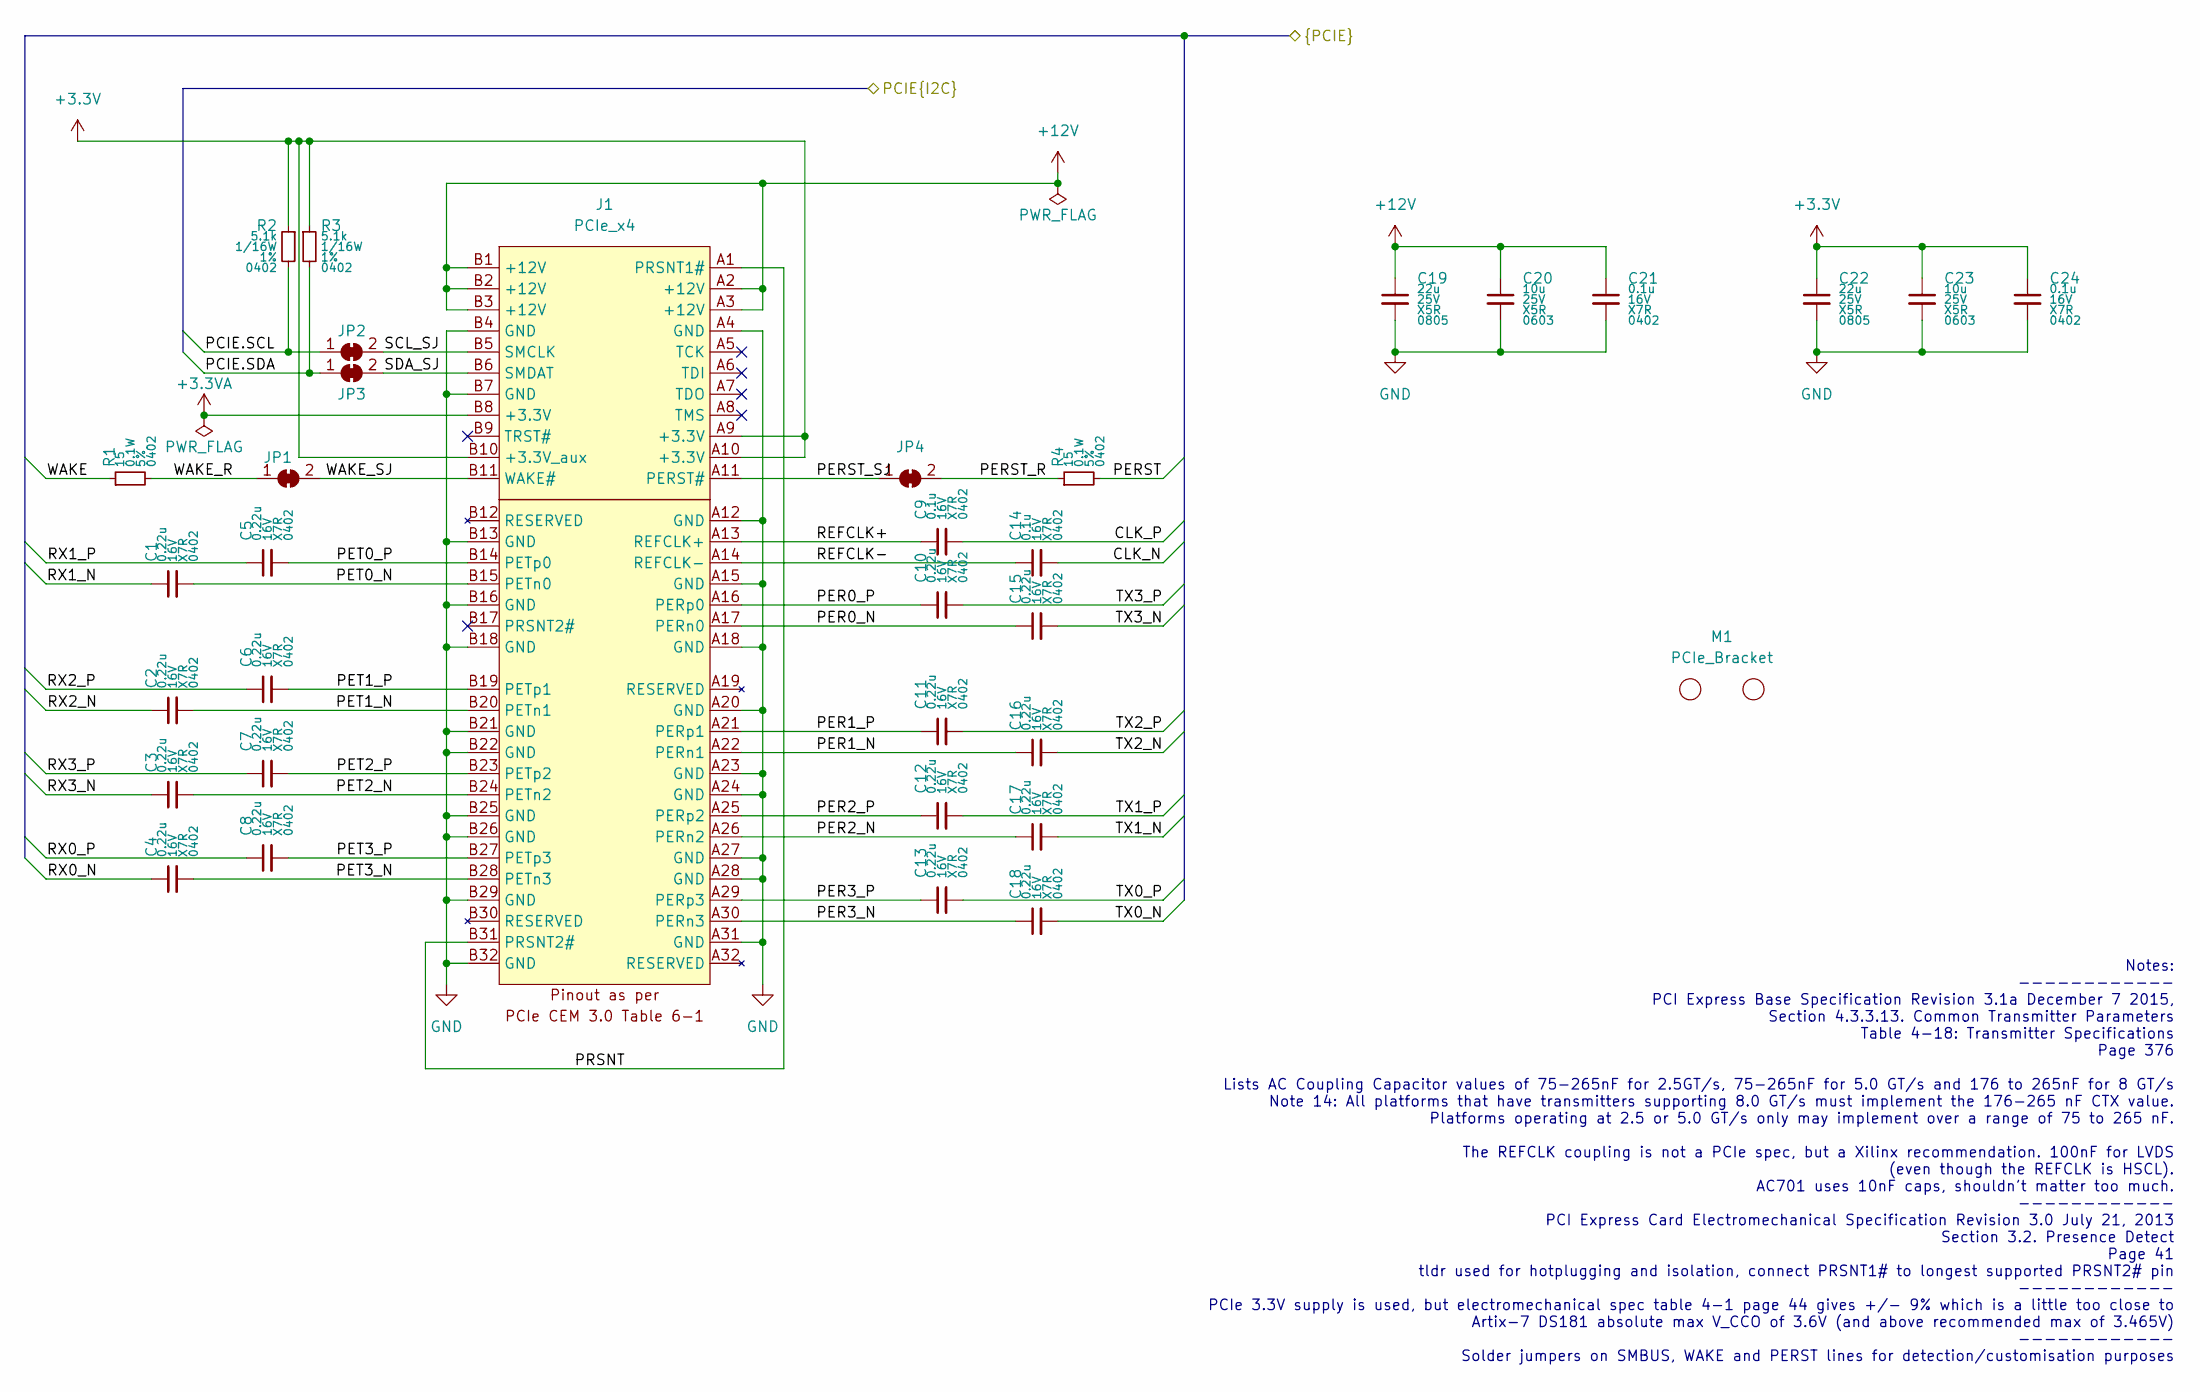
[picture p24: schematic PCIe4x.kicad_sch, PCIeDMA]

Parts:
C1, C2, C3, C4, C5, C6, C7, C8, C10, C11, C12, C13, C15, C16, C17, C18: 0.22u; C_0402_1005Metric; Rating 16V
C9, C14, C21, C24: 0.1u; C_0402_1005Metric; Rating 16V
C19, C22: 22u; C_0805_2012Metric; Rating 25V
C20, C23: 10u; C_0603_1608Metric; Rating 25V
J1: PCIe_x4; BUS_PCIexpress_x4
JP1, JP2, JP3, JP4: SolderJumper_2_Bridged; SolderJumper-2_P1.3mm_Bridged_RoundedPad1.0x1.5mm
M1: PCIe_Bracket
R1, R4: 15; R_0402_1005Metric; Rating 0.1W; Tolerance 5%
R2, R3: 5.1k; R_0402_1005Metric; Rating 1/16W; Tolerance 1%

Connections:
+3.3V: C22.1, C23.1, C24.1, J1.A9 (+3.3V), J1.A10 (+3.3V), J1.B10 (+3.3V_aux), R2.1, R3.1; also elsewhere on the board
+3.3VA: J1.B8 (+3.3V)
+12V: C19.1, C20.1, C21.1, J1.A2 (+12V), J1.A3 (+12V), J1.B1 (+12V), J1.B2 (+12V), J1.B3 (+12V); also elsewhere on the board
/FPGA/CLK_N: C14.2; also elsewhere on the board
/FPGA/CLK_P: C9.2; also elsewhere on the board
/FPGA/PCIE.SCL: JP2.1 (A), R2.2; also elsewhere on the board
/FPGA/PCIE.SDA: JP3.1 (A), R3.2; also elsewhere on the board
/FPGA/PERST: R4.2; also elsewhere on the board
/FPGA/RX0_N: C4.1; also elsewhere on the board
/FPGA/RX0_P: C8.1; also elsewhere on the board
/FPGA/RX1_N: C1.1; also elsewhere on the board
/FPGA/RX1_P: C5.1; also elsewhere on the board
/FPGA/RX2_N: C2.1; also elsewhere on the board
/FPGA/RX2_P: C6.1; also elsewhere on the board
/FPGA/RX3_N: C3.1; also elsewhere on the board
/FPGA/RX3_P: C7.1; also elsewhere on the board
/FPGA/TX0_N: C18.2; also elsewhere on the board
/FPGA/TX0_P: C13.2; also elsewhere on the board
/FPGA/TX1_N: C17.2; also elsewhere on the board
/FPGA/TX1_P: C12.2; also elsewhere on the board
/FPGA/TX2_N: C16.2; also elsewhere on the board
/FPGA/TX2_P: C11.2; also elsewhere on the board
/FPGA/TX3_N: C15.2; also elsewhere on the board
/FPGA/TX3_P: C10.2; also elsewhere on the board
/FPGA/WAKE: R1.1; also elsewhere on the board
/PCIe 4x/PER0_N: C15.1, J1.A17 (PERn0)
/PCIe 4x/PER0_P: C10.1, J1.A16 (PERp0)
/PCIe 4x/PER1_N: C16.1, J1.A22 (PERn1)
/PCIe 4x/PER1_P: C11.1, J1.A21 (PERp1)
/PCIe 4x/PER2_N: C17.1, J1.A26 (PERn2)
/PCIe 4x/PER2_P: C12.1, J1.A25 (PERp2)
/PCIe 4x/PER3_N: C18.1, J1.A30 (PERn3)
/PCIe 4x/PER3_P: C13.1, J1.A29 (PERp3)
/PCIe 4x/PERST_R: JP4.2 (B), R4.1
/PCIe 4x/PERST_SJ: J1.A11 (PERST#), JP4.1 (A)
/PCIe 4x/PET0_N: C1.2, J1.B15 (PETn0)
/PCIe 4x/PET0_P: C5.2, J1.B14 (PETp0)
/PCIe 4x/PET1_N: C2.2, J1.B20 (PETn1)
/PCIe 4x/PET1_P: C6.2, J1.B19 (PETp1)
/PCIe 4x/PET2_N: C3.2, J1.B24 (PETn2)
/PCIe 4x/PET2_P: C7.2, J1.B23 (PETp2)
/PCIe 4x/PET3_N: C4.2, J1.B28 (PETn3)
/PCIe 4x/PET3_P: C8.2, J1.B27 (PETp3)
/PCIe 4x/PRSNT: J1.A1 (PRSNT1#), J1.B31 (PRSNT2#)
/PCIe 4x/REFCLK+: C9.1, J1.A13 (REFCLK+)
/PCIe 4x/REFCLK-: C14.1, J1.A14 (REFCLK-)
/PCIe 4x/SCL_SJ: J1.B5 (SMCLK), JP2.2 (B)
/PCIe 4x/SDA_SJ: J1.B6 (SMDAT), JP3.2 (B)
/PCIe 4x/WAKE_R: JP1.1 (A), R1.2
/PCIe 4x/WAKE_SJ: J1.B11 (WAKE#), JP1.2 (B)
GND: C19.2, C20.2, C21.2, C22.2, C23.2, C24.2, J1.A4 (GND), J1.A12 (GND), J1.A15 (GND), J1.A18 (GND), J1.A20 (GND), J1.A23 (GND), J1.A24 (GND), J1.A27 (GND), J1.A28 (GND), J1.A31 (GND), J1.B4 (GND), J1.B7 (GND), J1.B13 (GND), J1.B16 (GND), J1.B18 (GND), J1.B21 (GND), J1.B22 (GND), J1.B25 (GND), J1.B26 (GND), J1.B29 (GND), J1.B32 (GND); also elsewhere on the board

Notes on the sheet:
Notes: ------------ PCI Express Base Specification Revision 3.1a December 7 2015, Section 4.3.3.13. Common Transmitter Parameters Table 4-18: Transmitter Specifications Page 376 Lists AC Coupling Capacitor values of 75-265nF for 2.5GT/s, 75-265nF for 5.0 GT/s and 176 to 265nF for 8 GT/s Note 14: Al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

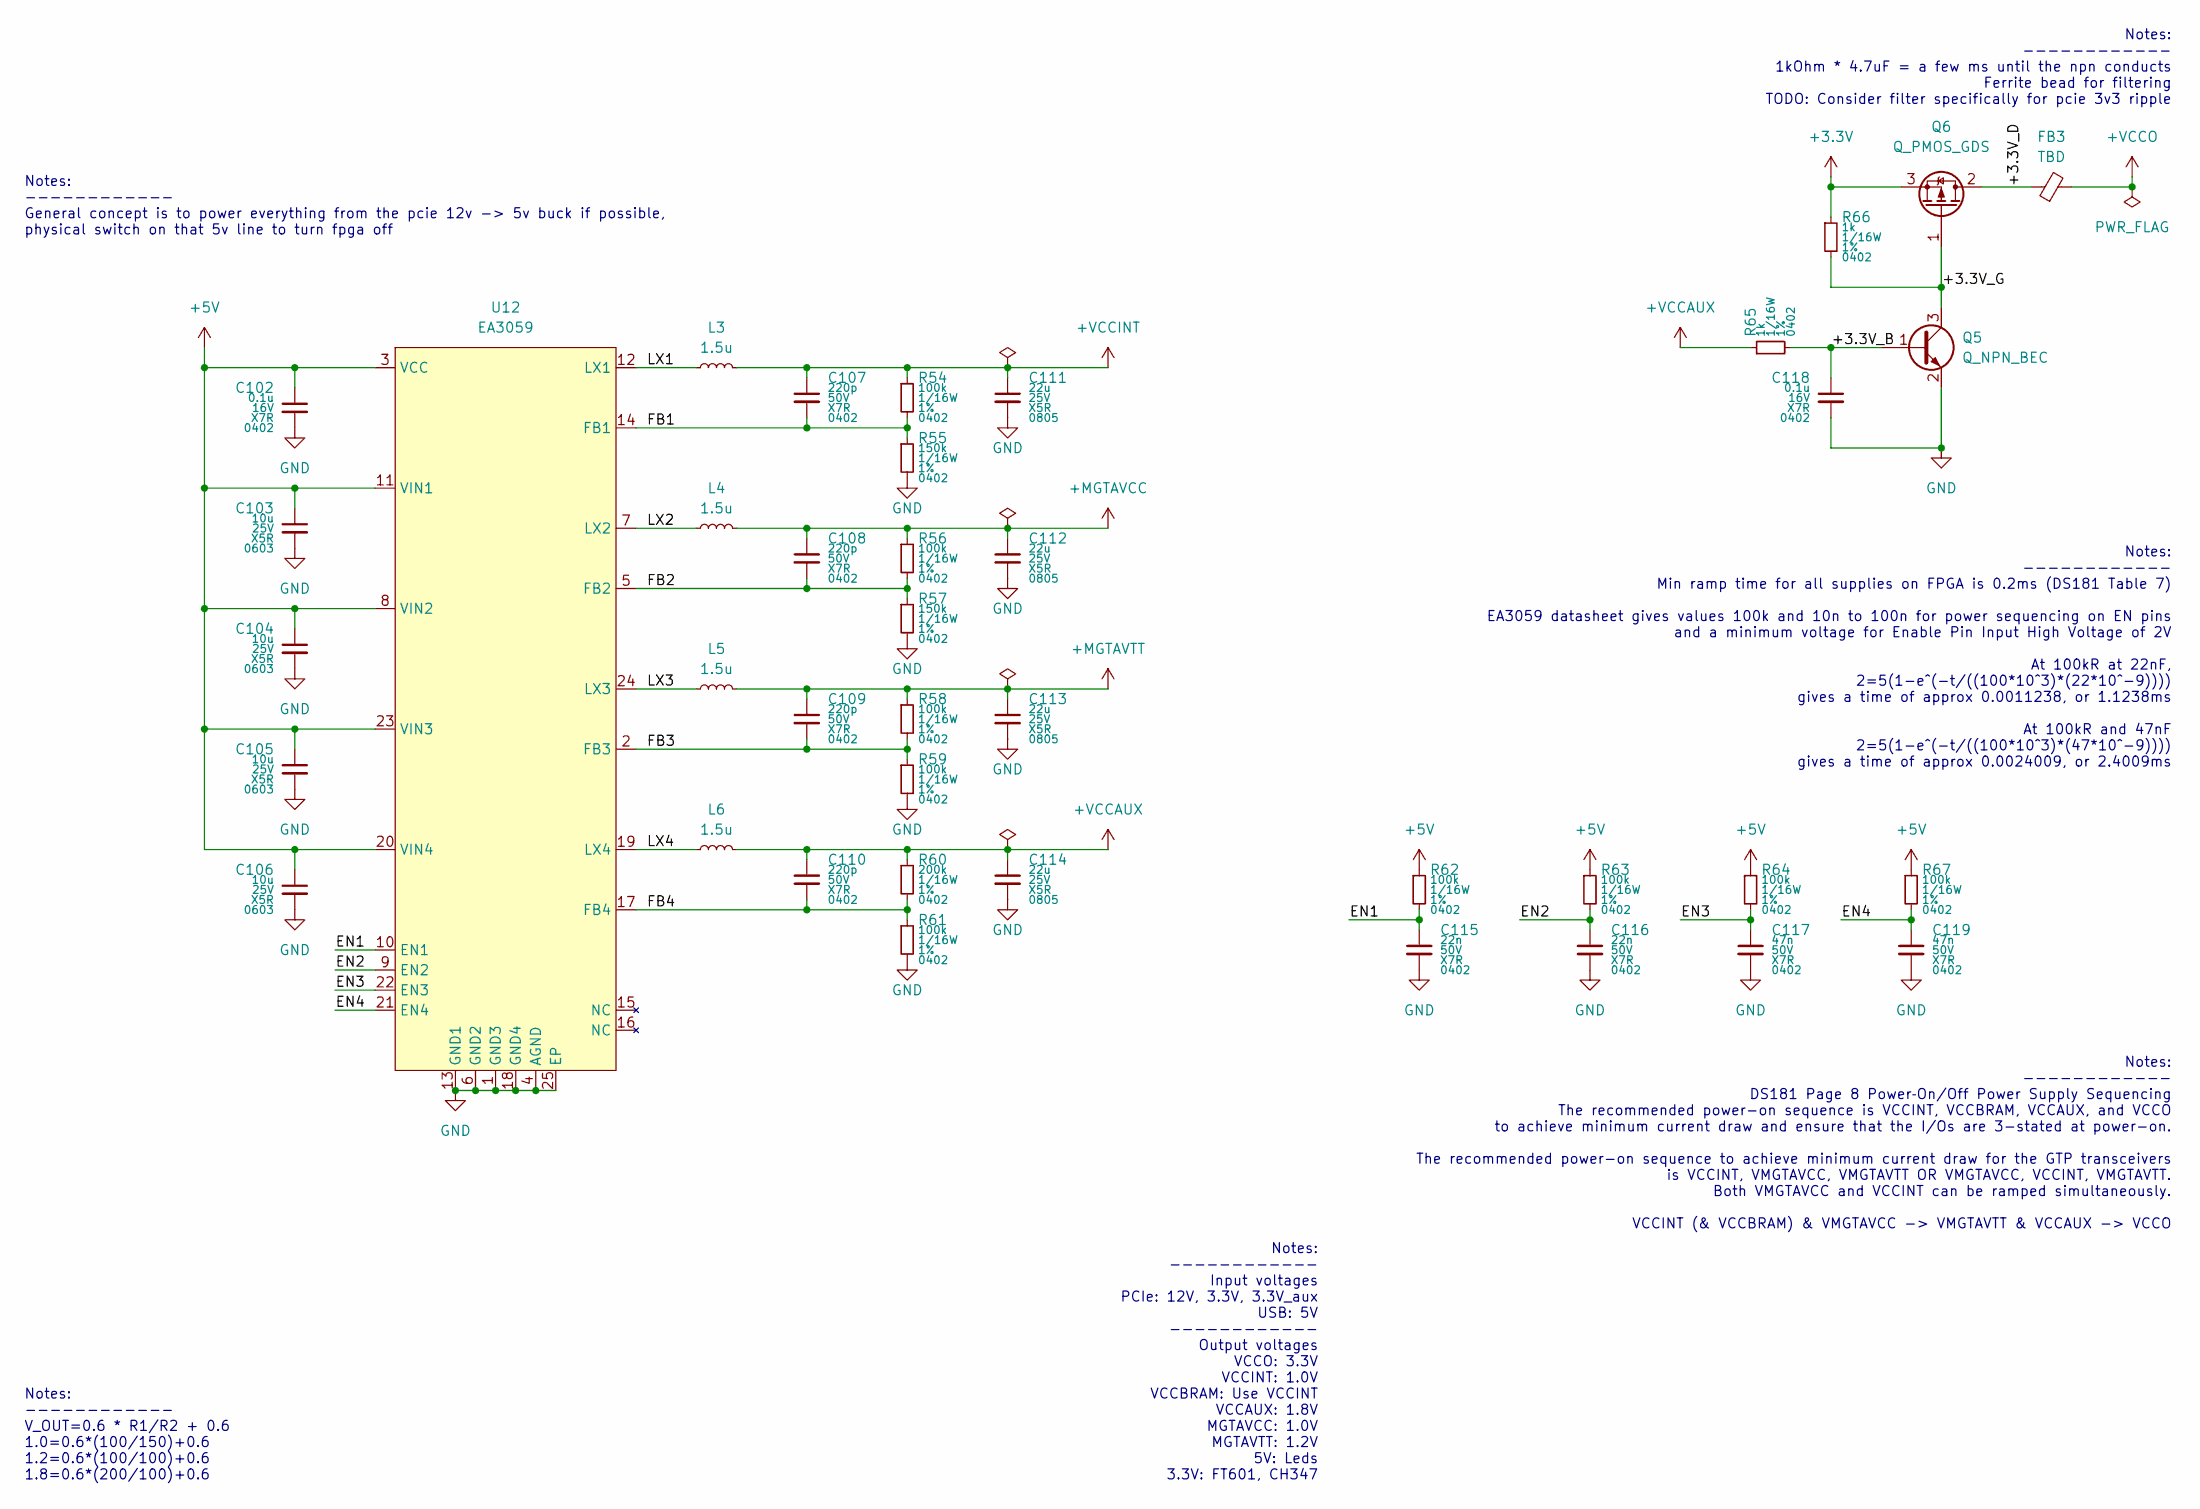
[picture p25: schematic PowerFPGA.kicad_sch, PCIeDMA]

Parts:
C102, C118: 0.1u; C_0402_1005Metric; Rating 16V
C103, C104, C105, C106: 10u; C_0603_1608Metric; Rating 25V
C107, C108, C109, C110: 220p; C_0402_1005Metric; Rating 50V
C111, C112, C113, C114: 22u; C_0805_2012Metric; Rating 25V
C115, C116: 22n; C_0402_1005Metric; Rating 50V
C117, C119: 47n; C_0402_1005Metric; Rating 50V
FB3: TBD; L_0805_2012Metric
L3, L4, L5, L6: 1.5u; L_Abracon_ASPI-3012S
Q5: Q_NPN_BEC; SOT-23
Q6: Q_PMOS_GDS; SOT-23
R54, R56, R58, R59, R61, R62, R63, R64, R67: 100k; R_0402_1005Metric; Rating 1/16W; Tolerance 1%
R55, R57: 150k; R_0402_1005Metric; Rating 1/16W; Tolerance 1%
R60: 200k; R_0402_1005Metric; Rating 1/16W; Tolerance 1%
R65, R66: 1k; R_0402_1005Metric; Rating 1/16W; Tolerance 1%
U12: EA3059; QFN-24-1EP_4x4mm_P0.5mm_EP2.6x2.6mm

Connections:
+3.3V: Q6.3 (S), R66.1; also elsewhere on the board
+5V: C102.1, C103.1, C104.1, C105.1, C106.1, R62.1, R63.1, R64.1, R67.1, U12.3 (VCC), U12.8 (VIN2), U12.11 (VIN1), U12.20 (VIN4), U12.23 (VIN3); also elsewhere on the board
+MGTAVCC: C108.1, C112.1, L4.2, R56.1; also elsewhere on the board
+MGTAVTT: C109.1, C113.1, L5.2, R58.1; also elsewhere on the board
+VCCAUX: C110.1, C114.1, L6.2, R60.1, R65.1; also elsewhere on the board
+VCCINT: C107.1, C111.1, L3.2, R54.1; also elsewhere on the board
+VCCO: FB3.2; also elsewhere on the board
/FPGA Power/+3.3V_B: C118.1, Q5.1 (B), R65.2
/FPGA Power/+3.3V_D: FB3.1, Q6.2 (D)
/FPGA Power/+3.3V_G: Q5.3 (C), Q6.1 (G), R66.2
/FPGA Power/EN1: C115.1, R62.2, U12.10 (EN1)
/FPGA Power/EN2: C116.1, R63.2, U12.9 (EN2)
/FPGA Power/EN3: C117.1, R64.2, U12.22 (EN3)
/FPGA Power/EN4: C119.1, R67.2, U12.21 (EN4)
/FPGA Power/FB1: C107.2, R54.2, R55.1, U12.14 (FB1)
/FPGA Power/FB2: C108.2, R56.2, R57.1, U12.5 (FB2)
/FPGA Power/FB3: C109.2, R58.2, R59.1, U12.2 (FB3)
/FPGA Power/FB4: C110.2, R60.2, R61.1, U12.17 (FB4)
/FPGA Power/LX1: L3.1, U12.12 (LX1)
/FPGA Power/LX2: L4.1, U12.7 (LX2)
/FPGA Power/LX3: L5.1, U12.24 (LX3)
/FPGA Power/LX4: L6.1, U12.19 (LX4)
GND: C102.2, C103.2, C104.2, C105.2, C106.2, C111.2, C112.2, C113.2, C114.2, C115.2, C116.2, C117.2, C118.2, C119.2, Q5.2 (E), R55.2, R57.2, R59.2, R61.2, U12.1 (GND3), U12.4 (AGND), U12.6 (GND2), U12.13 (GND1), U12.18 (GND4), U12.25 (EP); also elsewhere on the board

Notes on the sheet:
Notes: ------------ V_OUT=0.6 * R1/R2 + 0.6 1.0=0.6*(100/150)+0.6 1.2=0.6*(100/100)+0.6 1.8=0.6*(200/100)+0.6
Notes: ------------ General concept is to power everything from the pcie 12v -> 5v buck if possible, physical switch on that 5v line to turn fpga off
Notes: ------------ 1kOhm * 4.7uF = a few ms until the npn conducts Ferrite bead for filtering TODO: Consider filter specifically for pcie 3v3 ripple
Notes: ------------ DS181 Page 8 Power‐On/Off Power Supply Sequencing The recommended power-on sequence is VCCINT, VCCBRAM, VCCAUX, and VCCO to achieve minimum current draw and ensure that the I/Os are 3-stated at power-on. The recommended power-on sequence to achieve minimum current draw for the G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
Notes: ------------ Min ramp time for all supplies on FPGA is 0.2ms (DS181 Table 7) EA3059 datasheet gives values 100k and 10n to 100n for power sequencing on EN pins and a minimum voltage for Enable Pin Input High Voltage of 2V At 100kR at 22nF, 2=5(1-e^(-t/((100*10^3)*(22*10^-9)))) gives a time o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
Notes: ------------ Input voltages PCIe: 12V, 3.3V, 3.3V_aux USB: 5V ------------ Output voltages VCCO: 3.3V VCCINT: 1.0V VCCBRAM: Use VCCINT VCCAUX: 1.8V MGTAVCC: 1.0V MGTAVTT: 1.2V 5V: Leds 3.3V: FT601, CH347

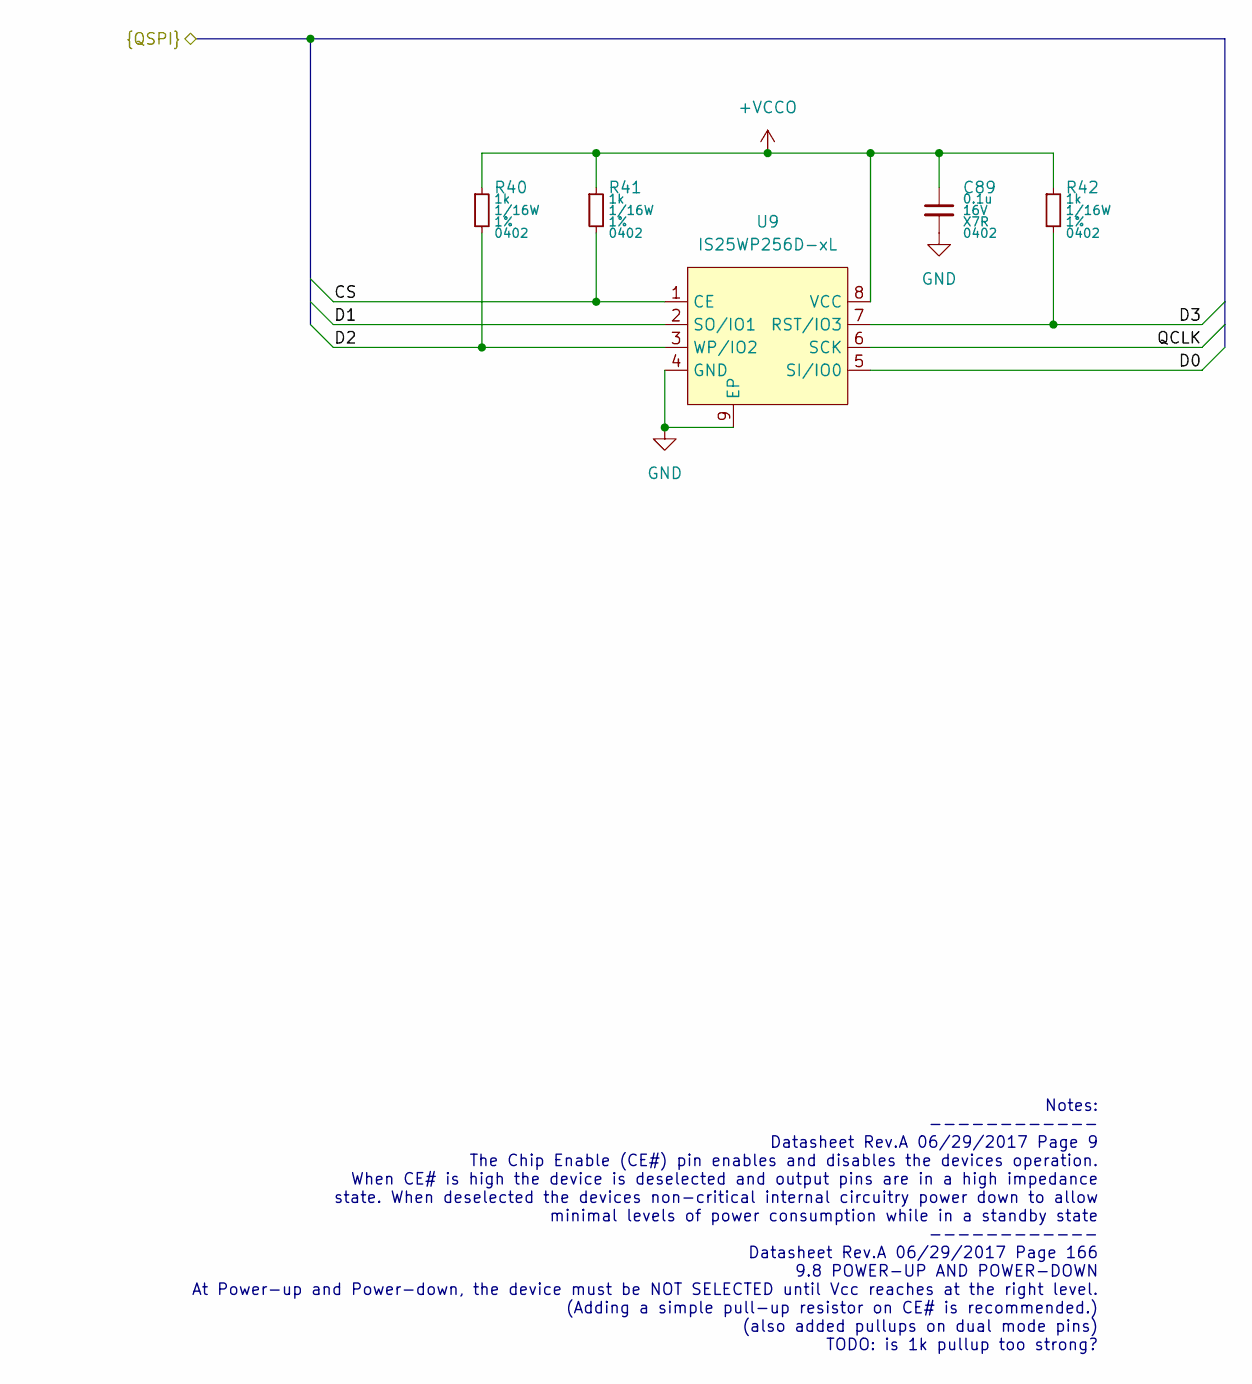
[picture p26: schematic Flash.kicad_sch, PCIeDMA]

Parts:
C89: 0.1u; C_0402_1005Metric; Rating 16V
R40, R41, R42: 1k; R_0402_1005Metric; Rating 1/16W; Tolerance 1%
U9: IS25WP256D-xL; WSON-8-1EP_8x6mm_P1.27mm_EP3.4x4.3mm

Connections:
+VCCO: C89.1, R40.1, R41.1, R42.1, U9.8 (VCC); also elsewhere on the board
/FPGA/CS: R41.2, U9.1 (CE); also elsewhere on the board
/FPGA/D0: U9.5 (SI/IO0); also elsewhere on the board
/FPGA/D1: U9.2 (SO/IO1); also elsewhere on the board
/FPGA/D2: R40.2, U9.3 (WP/IO2); also elsewhere on the board
/FPGA/D3: R42.2, U9.7 (RST/IO3); also elsewhere on the board
/FPGA/QCLK: U9.6 (SCK); also elsewhere on the board
GND: C89.2, U9.4 (GND), U9.9 (EP); also elsewhere on the board

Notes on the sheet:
Notes: ------------ Datasheet Rev.A 06/29/2017 Page 9 The Chip Enable (CE#) pin enables and disables the devices operation. When CE# is high the device is deselected and output pins are in a high impedance state. When deselected the devices non-critical internal circuitry power down to allow minima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

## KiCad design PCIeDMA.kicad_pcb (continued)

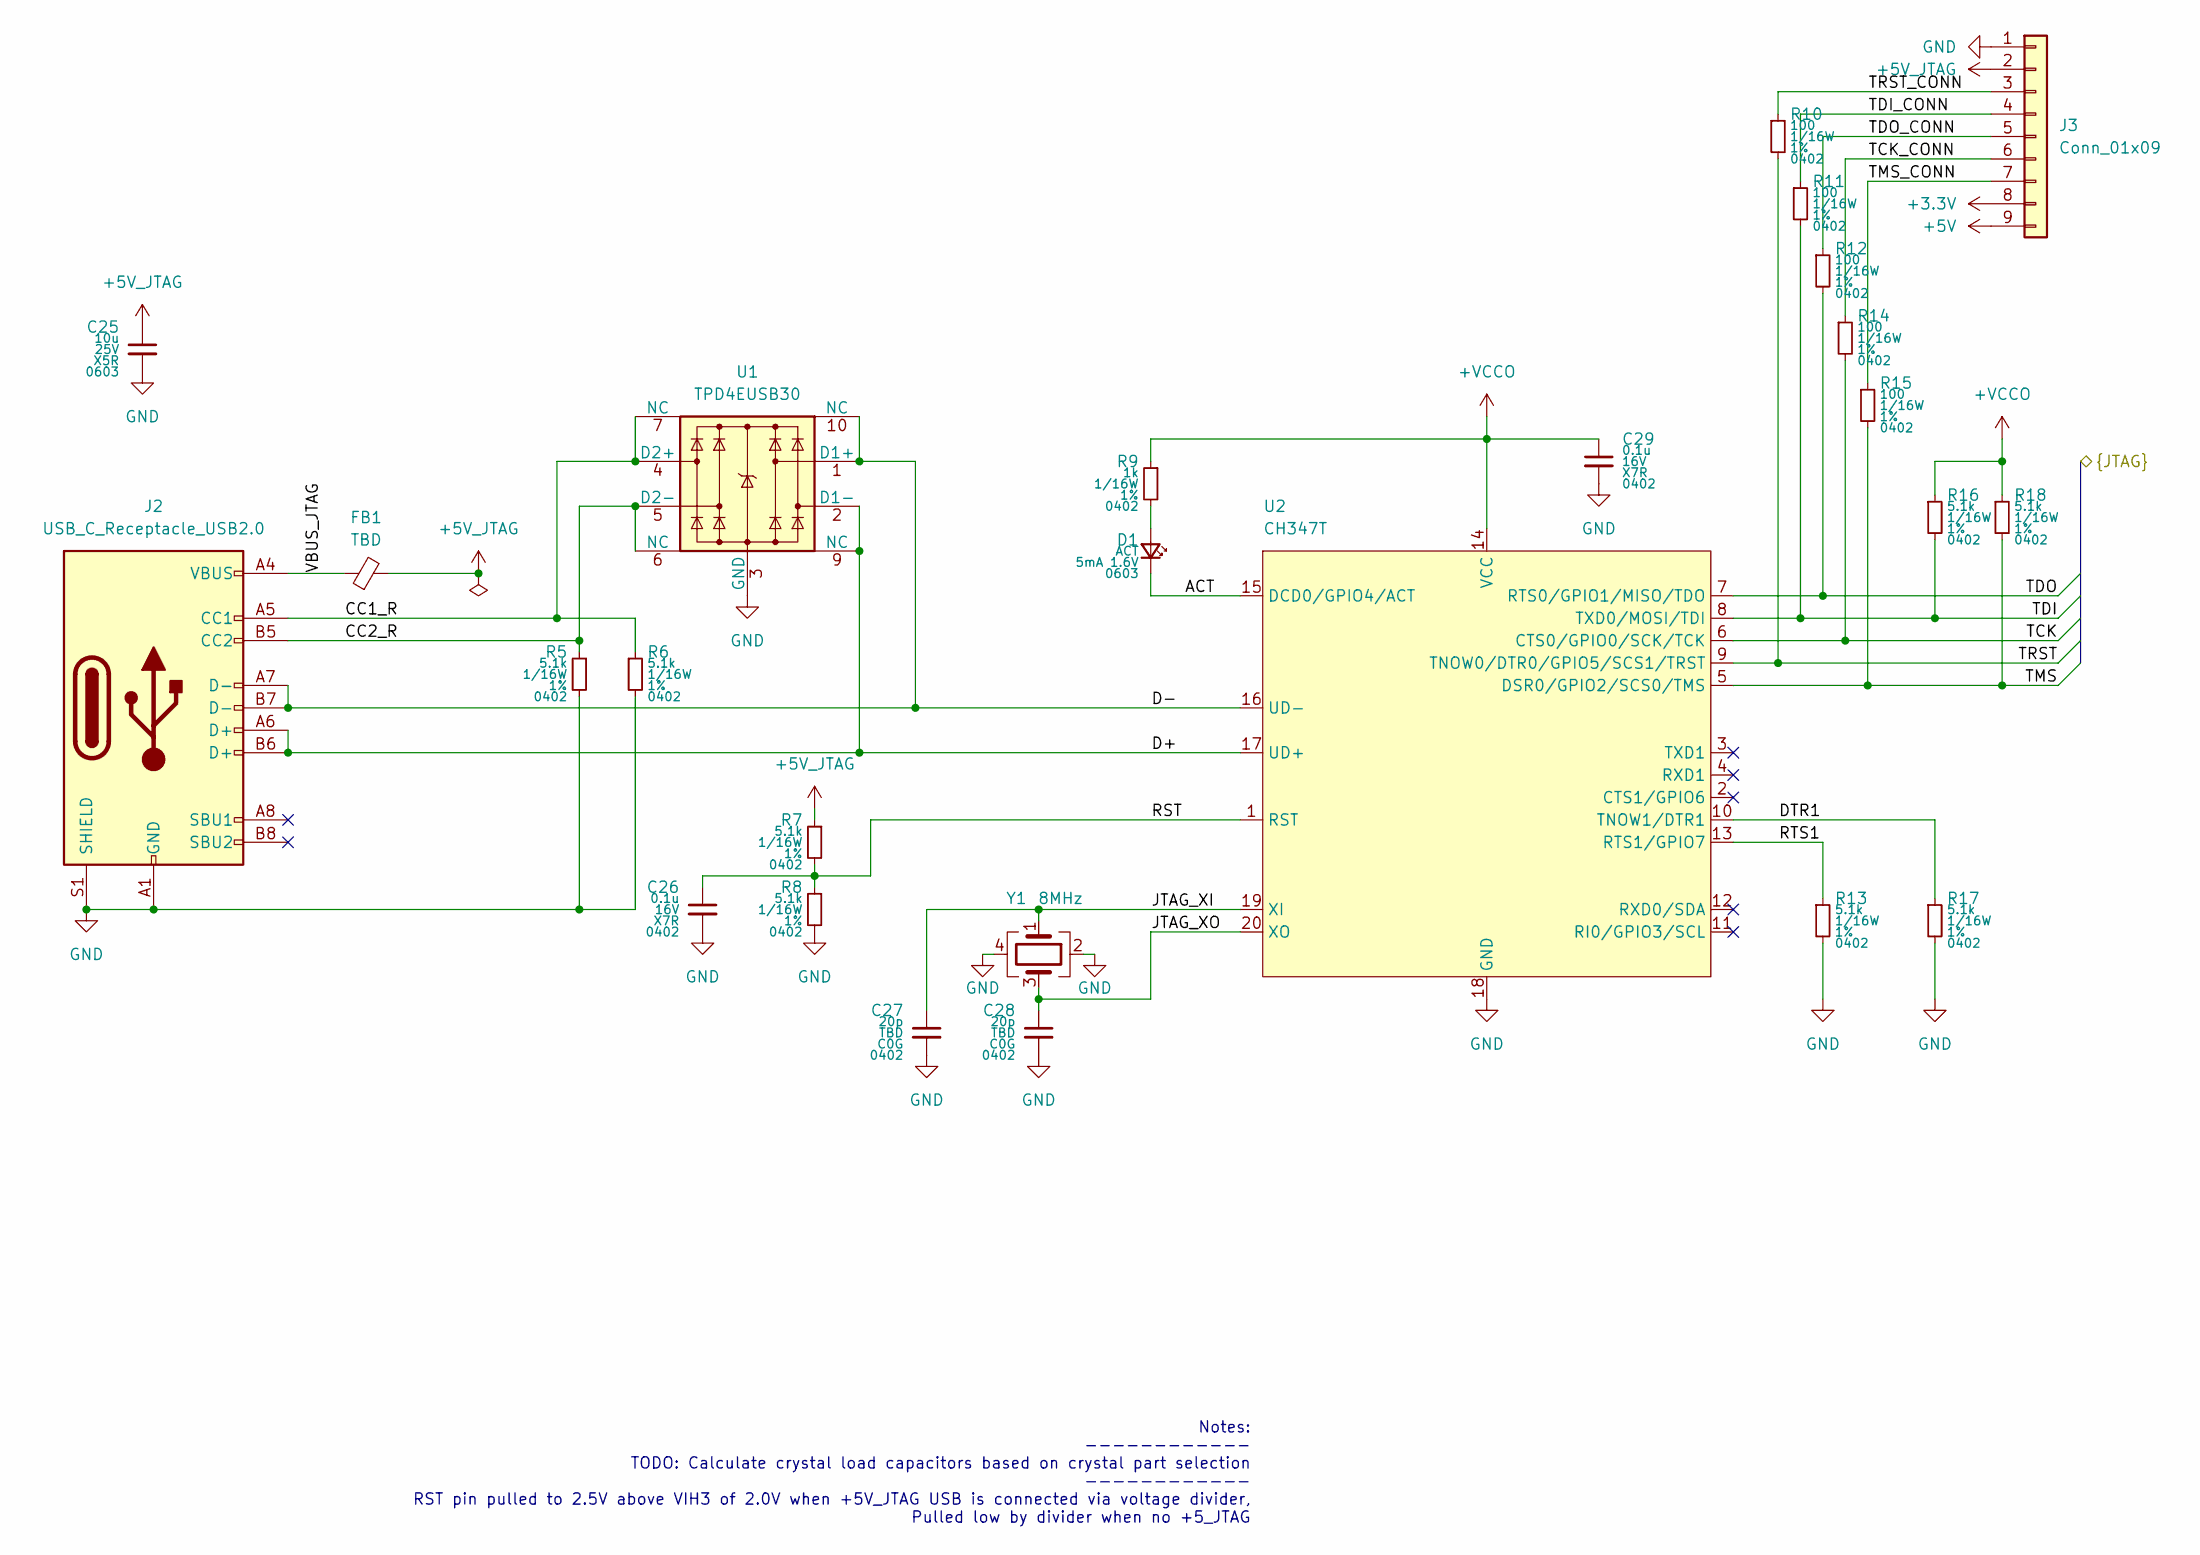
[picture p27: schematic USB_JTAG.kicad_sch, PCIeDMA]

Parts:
C25: 10u; C_0603_1608Metric; Rating 25V
C26, C29: 0.1u; C_0402_1005Metric; Rating 16V
C27, C28: 20p; C_0402_1005Metric; Rating TBD
D1: ACT; LED_0603_1608Metric; Rating 5mA 1.6V
FB1: TBD; L_0805_2012Metric
J2: USB_C_Receptacle_USB2.0; USB_C_Receptacle_HRO_TYPE-C-31-M-12
J3: Conn_01x09; PinHeader_1x09_P1.27mm_Vertical
R5, R6, R7, R8, R13, R16, R17, R18: 5.1k; R_0402_1005Metric; Rating 1/16W; Tolerance 1%
R9: 1k; R_0402_1005Metric; Rating 1/16W; Tolerance 1%
R10, R11, R12, R14, R15: 100; R_0402_1005Metric; Rating 1/16W; Tolerance 1%
U1: TPD4EUSB30; USON-10_2.5x1.0mm_P0.5mm
U2: CH347T; TSSOP-20_4.4x6.5mm_P0.65mm
Y1: 8MHz; Crystal_SMD_3225-4Pin_3.2x2.5mm

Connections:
+3.3V: J3.8; also elsewhere on the board
+5V: J3.9; also elsewhere on the board
+5V_JTAG: C25.1, FB1.2, J3.2, R7.1; also elsewhere on the board
+VCCO: C29.1, R9.1, R16.1, R18.1, U2.14 (VCC); also elsewhere on the board
/FPGA/TCK: R14.2, U2.6 (CTS0/GPIO0/SCK/TCK); also elsewhere on the board
/FPGA/TDI: R11.2, R16.2, U2.8 (TXD0/MOSI/TDI); also elsewhere on the board
/FPGA/TDO: R12.2, U2.7 (RTS0/GPIO1/MISO/TDO); also elsewhere on the board
/FPGA/TMS: R15.2, R18.2, U2.5 (DSR0/GPIO2/SCS0/TMS); also elsewhere on the board
/FPGA/TRST: R10.2, U2.9 (TNOW0/DTR0/GPIO5/SCS1/TRST); also elsewhere on the board
/USB JTAG/ACT: D1.1 (K), U2.15 (DCD0/GPIO4/ACT)
/USB JTAG/CC1_R: J2.A5 (CC1), R6.1, U1.4 (D2+), U1.7 (NC)
/USB JTAG/CC2_R: J2.B5 (CC2), R5.1, U1.5 (D2-), U1.6 (NC)
/USB JTAG/D+: J2.A6 (D+), J2.B6 (D+), U1.2 (D1-), U1.9 (NC), U2.17 (UD+)
/USB JTAG/D-: J2.A7 (D-), J2.B7 (D-), U1.1 (D1+), U1.10 (NC), U2.16 (UD-)
/USB JTAG/DTR1: R17.1, U2.10 (TNOW1/DTR1)
/USB JTAG/JTAG_XI: C27.1, U2.19 (XI), Y1.1
/USB JTAG/JTAG_XO: C28.1, U2.20 (XO), Y1.3
/USB JTAG/RST: C26.1, R7.2, R8.1, U2.1 (RST)
/USB JTAG/RTS1: R13.1, U2.13 (RTS1/GPIO7)
/USB JTAG/TCK_CONN: J3.6, R14.1
/USB JTAG/TDI_CONN: J3.4, R11.1
/USB JTAG/TDO_CONN: J3.5, R12.1
/USB JTAG/TMS_CONN: J3.7, R15.1
/USB JTAG/TRST_CONN: J3.3, R10.1
/USB JTAG/VBUS_JTAG: FB1.1, J2.A4 (VBUS), J2.A9 (VBUS), J2.B4 (VBUS), J2.B9 (VBUS)
GND: C25.2, C26.2, C27.2, C28.2, C29.2, J2.A1 (GND), J2.A12 (GND), J2.B1 (GND), J2.B12 (GND), J2.S1 (SHIELD), J3.1, R5.2, R6.2, R8.2, R13.2, R17.2, U1.3 (GND), U1.8 (GND), U2.18 (GND), Y1.2, Y1.4; also elsewhere on the board
unnamed: D1.2 (A), R9.2

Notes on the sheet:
Notes: ------------ TODO: Calculate crystal load capacitors based on crystal part selection ------------ RST pin pulled to 2.5V above VIH3 of 2.0V when +5V_JTAG USB is connected via voltage divider, Pulled low by divider when no +5_JTAG

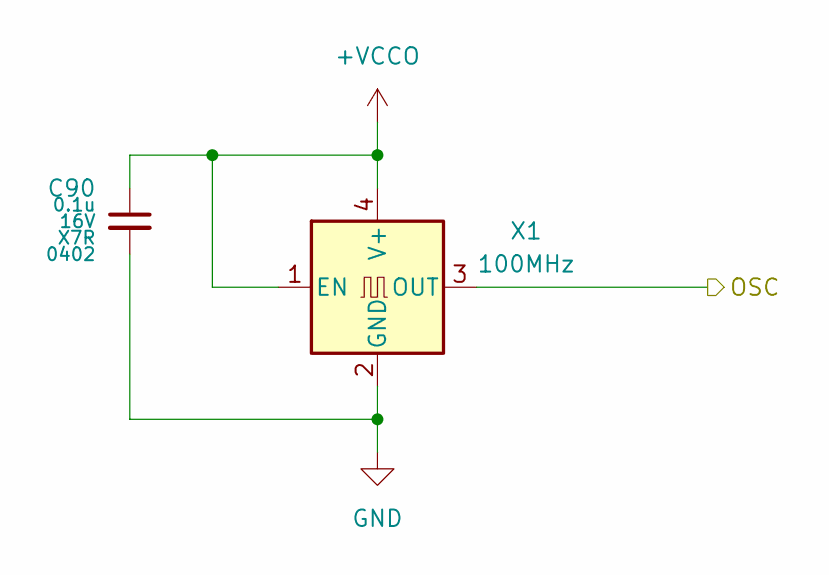
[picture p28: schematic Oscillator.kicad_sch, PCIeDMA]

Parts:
C90: 0.1u; C_0402_1005Metric; Rating 16V
X1: 100MHz; Crystal_SMD_3225-4Pin_3.2x2.5mm

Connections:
+VCCO: C90.1, X1.1 (EN), X1.4 (V+); also elsewhere on the board
/FPGA/OSC: X1.3 (OUT); also elsewhere on the board
GND: C90.2, X1.2 (GND); also elsewhere on the board

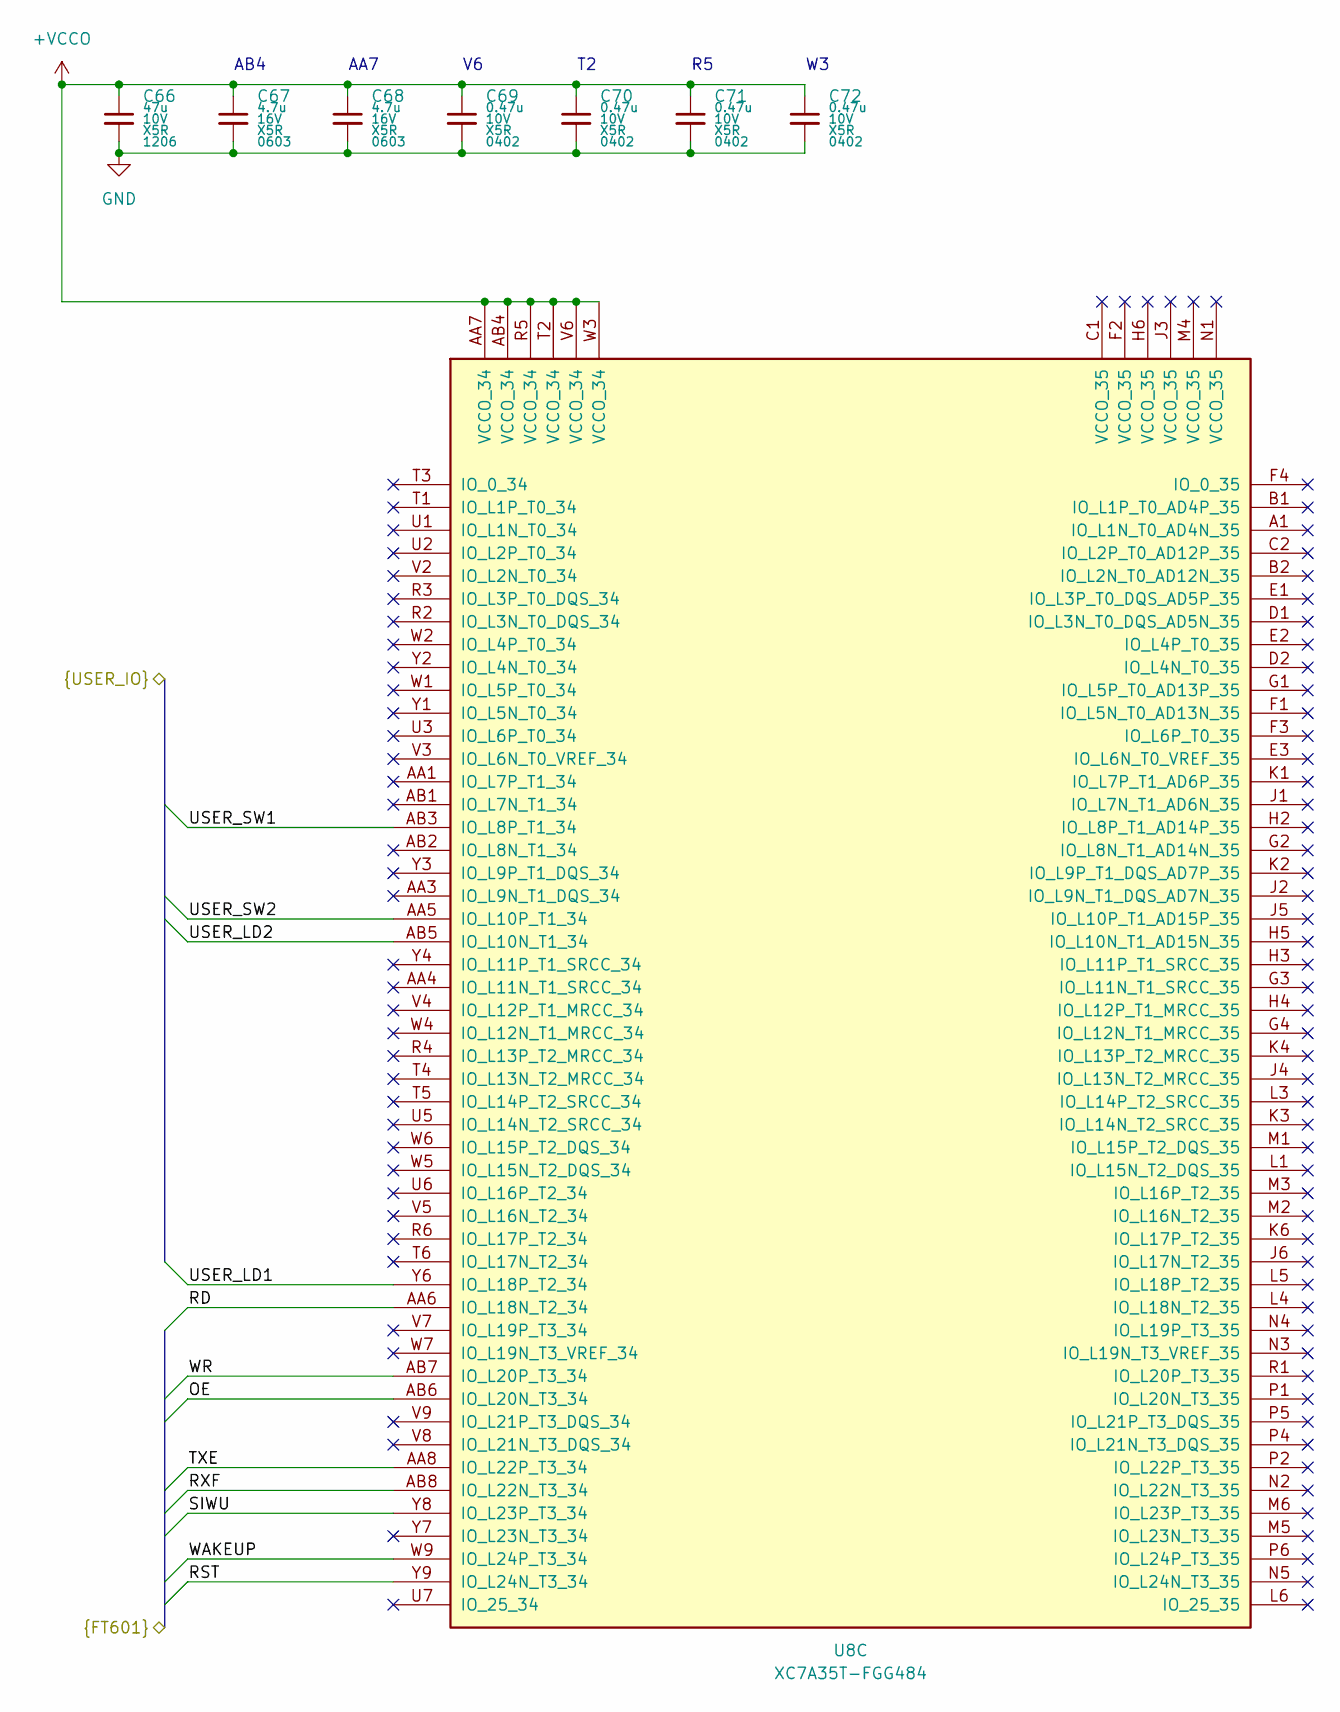
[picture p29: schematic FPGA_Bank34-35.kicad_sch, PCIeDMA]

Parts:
C66: 47u; C_1206_3216Metric; Rating 10V
C67, C68: 4.7u; C_0603_1608Metric; Rating 16V
C69, C70, C71, C72: 0.47u; C_0402_1005Metric; Rating 10V
U8: XC7A35T-FGG484; Xilinx_FGG484

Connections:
+VCCO: C66.1, C67.1, C68.1, C69.1, C70.1, C71.1, C72.1, U8.AA7 (VCCO_34), U8.AB4 (VCCO_34), U8.R5 (VCCO_34), U8.T2 (VCCO_34), U8.V6 (VCCO_34), U8.W3 (VCCO_34); also elsewhere on the board
/FPGA/OE: U8.AB6 (IO_L20N_T3_34); also elsewhere on the board
/FPGA/RD: U8.AA6 (IO_L18N_T2_34); also elsewhere on the board
/FPGA/RST: U8.Y9 (IO_L24N_T3_34); also elsewhere on the board
/FPGA/RXF: U8.AB8 (IO_L22N_T3_34); also elsewhere on the board
/FPGA/SIWU: U8.Y8 (IO_L23P_T3_34); also elsewhere on the board
/FPGA/TXE: U8.AA8 (IO_L22P_T3_34); also elsewhere on the board
/FPGA/USER_LD1: U8.Y6 (IO_L18P_T2_34); also elsewhere on the board
/FPGA/USER_LD2: U8.AB5 (IO_L10N_T1_34); also elsewhere on the board
/FPGA/USER_SW1: U8.AB3 (IO_L8P_T1_34); also elsewhere on the board
/FPGA/USER_SW2: U8.AA5 (IO_L10P_T1_34); also elsewhere on the board
/FPGA/WAKEUP: U8.W9 (IO_L24P_T3_34); also elsewhere on the board
/FPGA/WR: U8.AB7 (IO_L20P_T3_34); also elsewhere on the board
GND: C66.2, C67.2, C68.2, C69.2, C70.2, C71.2, C72.2; also elsewhere on the board

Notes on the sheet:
AB4
AA7

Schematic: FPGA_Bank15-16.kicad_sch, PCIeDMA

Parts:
C51: 47u; C_1206_3216Metric; Rating 10V
C52, C53: 4.7u; C_0603_1608Metric; Rating 16V
C54, C55, C56, C57: 0.47u; C_0402_1005Metric; Rating 10V
U8: XC7A35T-FGG484; Xilinx_FGG484

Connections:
+VCCO: C51.1, C52.1, C53.1, C54.1, C55.1, C56.1, C57.1, U8.A17 (VCCO_16), U8.B14 (VCCO_16), U8.C21 (VCCO_16), U8.D18 (VCCO_16), U8.E15 (VCCO_16), U8.F22 (VCCO_16); also elsewhere on the board
/FPGA/OSC: U8.B17 (IO_L11P_T1_SRCC_16); also elsewhere on the board
/FPGA/PCIE.SCL: U8.A16 (IO_L9N_T1_DQS_16); also elsewhere on the board
/FPGA/PCIE.SDA: U8.A15 (IO_L9P_T1_DQS_16); also elsewhere on the board
/FPGA/PERST: U8.B13 (IO_L8N_T1_16); also elsewhere on the board
/FPGA/TRST: U8.F21 (IO_25_16); also elsewhere on the board
/FPGA/WAKE: U8.A14 (IO_L10N_T1_16); also elsewhere on the board
GND: C51.2, C52.2, C53.2, C54.2, C55.2, C56.2, C57.2; also elsewhere on the board

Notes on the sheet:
A17
D18
B14
E15
C21
F22
Notes: ------------ UG483: Table 2-2: Required PCB Capacitor Quantities per Device: Artix-7 Devices Page 16, row FGG484 XC7A35T VCCO (all other Banks, per Bank): 1x47uF, 2x4.7uF, 4x0.47uF ------------ UG483: Page 36 Power Supply Consolidation Powering 1.8V VCCO, VCCAUX, and VCCAUX_IO from a common 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

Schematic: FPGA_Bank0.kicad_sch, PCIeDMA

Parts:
C58: 47u; C_1206_3216Metric; Rating 10V
D4: DONE; LED_0603_1608Metric; Rating 5mA 1.6V
D5: INIT_B; LED_0603_1608Metric; Rating 5mA 1.6V
R31, R32, R33, R34, R35, R36, R37, R38: 1k; R_0402_1005Metric; Rating 1/16W; Tolerance 1%
SW3: PROGRAM; SW_SPST_B3U-1000P
SW4: INIT_B; SW_SPST_B3U-1000P
U8: XC7A35T-FGG484; Xilinx_FGG484

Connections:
+VCCO: C58.1, R31.1, R32.1, R33.1, R34.1, R37.1, R38.1, U8.F12 (VCCO_0), U8.T12 (VCCO_0), U8.U8 (CFGBVS_0); also elsewhere on the board
/FPGA/Bank 0/DONE: D4.1 (K), R32.2, U8.G11 (DONE_0)
/FPGA/Bank 0/INIT_B: D5.1 (K), R37.2, SW4.2, U8.U12 (INIT_B_0)
/FPGA/Bank 0/M0: R33.2, U8.U11 (M0_0)
/FPGA/Bank 0/M1: R35.1, U8.U10 (M1_0)
/FPGA/Bank 0/M2: R36.1, U8.U9 (M2_0)
/FPGA/Bank 0/PROGRAM_B: R31.2, SW3.2, U8.N12 (PROGRAM_B_0)
/FPGA/QCLK: U8.L12 (CCLK_0); also elsewhere on the board
/FPGA/TCK: U8.V12 (TCK_0); also elsewhere on the board
/FPGA/TDI: U8.R13 (TDI_0); also elsewhere on the board
/FPGA/TDO: U8.U13 (TDO_0); also elsewhere on the board
/FPGA/TMS: U8.T13 (TMS_0); also elsewhere on the board
GND: C58.2, R35.2, R36.2, SW3.1, SW4.1, U8.L9 (VREFN_0), U8.L10 (VP_0), U8.M9 (VN_0), U8.M10 (VREFP_0), U8.N9 (DXN_0), U8.N10 (DXP_0); also elsewhere on the board
unnamed: D4.2 (A), R34.2
unnamed: D5.2 (A), R38.2

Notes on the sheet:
Notes: ------------ UG470 Page 21 Table 2-4: Configuration Pin Definitions (Cont'd) Connect PROGRAM_B to an external ≤ 4.7 kΩ pull-up resistor to VCCO_0 to ensure a stable High input, and recommend push-button to GND to enable manual configuration reset. ------------ UG470 Page 21 Table 2-4: Config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
Notes: ------------ UG483: Table 2-2: Required PCB Capacitor Quantities per Device: Artix-7 Devices Page 16, row FGG484 XC7A35T VCCO (bank 0): 1x47uF ------------ UG470: Page 28 Configuration Banks Voltage Select CFGVBS pulled low for 1.8V or 1.5V JTAG operation ------------ UG470 Page 7 The specif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

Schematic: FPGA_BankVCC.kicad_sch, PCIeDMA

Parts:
C73: 100u; C_1206_3216Metric; Rating 6.3V
C74, C75: 47u; C_1206_3216Metric; Rating 10V
C76, C77, C79, C80: 4.7u; C_0603_1608Metric; Rating 16V
C78, C81, C82, C83, C84, C85, C86, C87, C88: 0.47u; C_0402_1005Metric; Rating 10V
U8: XC7A35T-FGG484; Xilinx_FGG484

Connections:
+VCCAUX: C74.1, C77.1, C80.1, C82.1, C84.1, C86.1, C87.1, C88.1, U8.H12 (VCCAUX), U8.K10 (VCCADC_0), U8.K12 (VCCAUX), U8.M12 (VCCAUX), U8.P12 (VCCAUX), U8.R11 (VCCAUX); also elsewhere on the board
+VCCINT: C73.1, C75.1, C76.1, C78.1, C79.1, C81.1, C83.1, C85.1, U8.H8 (VCCINT), U8.H10 (VCCINT), U8.J7 (VCCINT), U8.J9 (VCCINT), U8.J11 (VCCBRAM), U8.K8 (VCCINT), U8.L7 (VCCINT), U8.L11 (VCCBRAM), U8.M8 (VCCINT), U8.N7 (VCCINT), U8.N11 (VCCBRAM), U8.P8 (VCCINT), U8.P10 (VCCINT), U8.R7 (VCCINT), U8.R9 (VCCINT), U8.T8 (VCCINT), U8.T10 (VCCINT); also elsewhere on the board
GND: C73.2, C74.2, C75.2, C76.2, C77.2, C78.2, C79.2, C80.2, C81.2, C82.2, C83.2, C84.2, C85.2, C86.2, C87.2, C88.2, U8.A2 (GND), U8.A3 (GND), U8.A5 (GND), U8.A7 (GND), U8.A9 (GND), U8.A11 (GND), U8.A12 (GND), U8.A22 (GND), U8.AA2 (GND), U8.AA12 (GND), U8.AA22 (GND), U8.AB9 (GND), U8.AB19 (GND), U8.B3 (GND), U8.B12 (GND), U8.B19 (GND), U8.C3 (GND), U8.C6 (GND), U8.C10 (GND), U8.C12 (GND), U8.C16 (GND), U8.D3 (GND), U8.D4 (GND), U8.D8 (GND), U8.D12 (GND), U8.D13 (GND), U8.E4 (GND), U8.E5 (GND), U8.E7 (GND), U8.E9 (GND), U8.E11 (GND), U8.E12 (VCCBATT_0), U8.E20 (GND), U8.F5 (GND), U8.F11 (GND), U8.F17 (GND), U8.G5 (GND), U8.G6 (GND), U8.G7 (GND), U8.G8 (GND), U8.G9 (GND), U8.G10 (GND), U8.G12 (GND), U8.G14 (GND), U8.H1 (GND), U8.H7 (GND), U8.H9 (GND), U8.H11 (GND), U8.H21 (GND), U8.J8 (GND), U8.J10 (GND), U8.J12 (GND), U8.J18 (GND), U8.K5 (GND), U8.K7 (GND), U8.K9 (GNDADC_0), U8.K11 (GND), U8.K15 (GND), U8.L2 (GND), U8.L8 (GND), U8.L22 (GND), U8.M7 (GND), U8.M11 (GND), U8.M19 (GND), U8.N6 (GND), U8.N8 (GND), U8.N16 (GND), U8.P3 (GND), U8.P7 (GND), U8.P9 (GND), U8.P11 (GND), U8.P13 (GND), U8.R8 (GND), U8.R10 (GND), U8.R12 (GND), U8.R20 (GND), U8.T7 (GND), U8.T9 (GND), U8.T11 (GND), U8.T17 (GND), U8.U4 (GND), U8.U14 (GND), U8.V1 (GND), U8.V11 (GND), U8.V21 (GND), U8.W8 (GND), U8.W18 (GND), U8.Y5 (GND), U8.Y15 (GND); also elsewhere on the board

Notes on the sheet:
K12
(For VCCBRAM)
Notes: ------------ UG483: Table 2-2: Required PCB Capacitor Quantities per Device: Artix-7 Devices Page 16, row FGG484 XC7A35T VCCINT: 1x100uF, 2x4.7uF, 3x0.47uF VCCBRAM: 1x47uF, 1x0.47uF VCCAUX: 1x47uF, 2x4.7uF, 5x0.47uF ------------ UG483: Page 19: Table 2-5: PCB Capacitor Specifications 100uF: 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
R11
H12
P12
J11
M12
K10

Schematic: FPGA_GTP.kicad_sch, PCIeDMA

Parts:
C45, C46, C49, C50: 0.1u; C_0402_1005Metric; Rating 16V
C47, C48: 4.7u; C_0603_1608Metric; Rating 16V
R30: 100; R_0402_1005Metric; Rating 1/16W; Tolerance 1%
U8: XC7A35T-FGG484; Xilinx_FGG484

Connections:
+MGTAVCC: C45.1, C46.1, C47.1, U8.D6 (MGTAVCC), U8.D10 (MGTAVCC), U8.E8 (MGTAVCC), U8.F7 (MGTAVCC), U8.F9 (MGTAVCC); also elsewhere on the board
+MGTAVTT: C48.1, C49.1, C50.1, R30.1, U8.B5 (MGTAVTT), U8.B7 (MGTAVTT), U8.B9 (MGTAVTT), U8.B11 (MGTAVTT), U8.C4 (MGTAVTT), U8.C8 (MGTAVTT); also elsewhere on the board
/FPGA/CLK_N: U8.E10 (MGTREFCLK1N_216); also elsewhere on the board
/FPGA/CLK_P: U8.F10 (MGTREFCLK1P_216); also elsewhere on the board
/FPGA/GTP/MGTRREF: R30.2, U8.F8 (MGTRREF_216)
/FPGA/RX0_N: U8.A8 (MGTPRXN0_216); also elsewhere on the board
/FPGA/RX0_P: U8.B8 (MGTPRXP0_216); also elsewhere on the board
/FPGA/RX1_N: U8.C11 (MGTPRXN1_216); also elsewhere on the board
/FPGA/RX1_P: U8.D11 (MGTPRXP1_216); also elsewhere on the board
/FPGA/RX2_N: U8.A10 (MGTPRXN2_216); also elsewhere on the board
/FPGA/RX2_P: U8.B10 (MGTPRXP2_216); also elsewhere on the board
/FPGA/RX3_N: U8.C9 (MGTPRXN3_216); also elsewhere on the board
/FPGA/RX3_P: U8.D9 (MGTPRXP3_216); also elsewhere on the board
/FPGA/TX0_N: U8.A4 (MGTPTXN0_216); also elsewhere on the board
/FPGA/TX0_P: U8.B4 (MGTPTXP0_216); also elsewhere on the board
/FPGA/TX1_N: U8.C5 (MGTPTXN1_216); also elsewhere on the board
/FPGA/TX1_P: U8.D5 (MGTPTXP1_216); also elsewhere on the board
/FPGA/TX2_N: U8.A6 (MGTPTXN2_216); also elsewhere on the board
/FPGA/TX2_P: U8.B6 (MGTPTXP2_216); also elsewhere on the board
/FPGA/TX3_N: U8.C7 (MGTPTXN3_216); also elsewhere on the board
/FPGA/TX3_P: U8.D7 (MGTPTXP3_216); also elsewhere on the board
GND: C45.2, C46.2, C47.2, C48.2, C49.2, C50.2; also elsewhere on the board

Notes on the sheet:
Notes: ------------ DS181 Page 2, Table 2: Recommended Operating Conditions VMGTAVCC: Typical 1.0V VMGTAVTT: Typical 1.2V ------------ UG482 Table 5-14: MGTRREF - Connect to a 100Ω resistor that is also connected to MGTAVTT Termination Resistor Calibration Circuit: The MGTRREF pin should be connect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
B11
D10

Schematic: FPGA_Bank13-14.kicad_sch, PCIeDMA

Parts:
C59: 47u; C_1206_3216Metric; Rating 10V
C60, C61: 4.7u; C_0603_1608Metric; Rating 16V
C62, C63, C64, C65: 0.47u; C_0402_1005Metric; Rating 10V
R39: 1k; R_0402_1005Metric; Rating 1/16W; Tolerance 1%
U8: XC7A35T-FGG484; Xilinx_FGG484

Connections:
+VCCO: C59.1, C60.1, C61.1, C62.1, C63.1, C64.1, C65.1, R39.1, U8.M14 (VCCO_14), U8.P18 (VCCO_14), U8.R15 (VCCO_14), U8.T22 (VCCO_14), U8.U19 (VCCO_14), U8.Y20 (VCCO_14); also elsewhere on the board
/FPGA/BE0: U8.Y18 (IO_L13P_T2_MRCC_14); also elsewhere on the board
/FPGA/BE1: U8.AA18 (IO_L17P_T2_A14_D30_14); also elsewhere on the board
/FPGA/BE2: U8.AB18 (IO_L17N_T2_A13_D29_14); also elsewhere on the board
/FPGA/BE3: U8.W17 (IO_L16N_T2_A15_D31_14); also elsewhere on the board
/FPGA/Bank 13-14/PUDC_B: R39.2, U8.U22 (IO_L3P_T0_DQS_PUDC_B_14)
/FPGA/CLK: U8.W19 (IO_L12P_T1_MRCC_14); also elsewhere on the board
/FPGA/CS: U8.T19 (IO_L6P_T0_FCS_B_14); also elsewhere on the board
/FPGA/D0: U8.P22 (IO_L1P_T0_D00_MOSI_14); also elsewhere on the board
/FPGA/D1: U8.R22 (IO_L1N_T0_D01_DIN_14); also elsewhere on the board
/FPGA/D2: U8.P21 (IO_L2P_T0_D02_14); also elsewhere on the board
/FPGA/D3: U8.R21 (IO_L2N_T0_D03_14); also elsewhere on the board
/FPGA/DATA0: U8.N13 (IO_L23P_T3_A03_D19_14); also elsewhere on the board
/FPGA/DATA1: U8.N14 (IO_L23N_T3_A02_D18_14); also elsewhere on the board
/FPGA/DATA2: U8.N15 (IO_25_14); also elsewhere on the board
/FPGA/DATA3: U8.P15 (IO_L22P_T3_A05_D21_14); also elsewhere on the board
/FPGA/DATA4: U8.P16 (IO_L24P_T3_A01_D17_14); also elsewhere on the board
/FPGA/DATA5: U8.N17 (IO_L21P_T3_DQS_14); also elsewhere on the board
/FPGA/DATA6: U8.P17 (IO_L21N_T3_DQS_A06_D22_14); also elsewhere on the board
/FPGA/DATA7: U8.R17 (IO_L24N_T3_A00_D16_14); also elsewhere on the board
/FPGA/DATA8: U8.P19 (IO_L5P_T0_D06_14); also elsewhere on the board
/FPGA/DATA9: U8.R18 (IO_L20P_T3_A08_D24_14); also elsewhere on the board
/FPGA/DATA10: U8.R19 (IO_L5N_T0_D07_14); also elsewhere on the board
/FPGA/DATA11: U8.T18 (IO_L20N_T3_A07_D23_14); also elsewhere on the board
/FPGA/DATA12: U8.U18 (IO_L18N_T2_A11_D27_14); also elsewhere on the board
/FPGA/DATA13: U8.V18 (IO_L14P_T2_SRCC_14); also elsewhere on the board
/FPGA/DATA14: U8.V19 (IO_L14N_T2_SRCC_14); also elsewhere on the board
/FPGA/DATA15: U8.V17 (IO_L16P_T2_CSI_B_14); also elsewhere on the board
/FPGA/DATA16: U8.W20 (IO_L12N_T1_MRCC_14); also elsewhere on the board
/FPGA/DATA17: U8.Y19 (IO_L13N_T2_MRCC_14); also elsewhere on the board
/FPGA/DATA18: U8.T21 (IO_L4P_T0_D04_14); also elsewhere on the board
/FPGA/DATA19: U8.T20 (IO_L6N_T0_D08_VREF_14); also elsewhere on the board
/FPGA/DATA20: U8.U21 (IO_L4N_T0_D05_14); also elsewhere on the board
/FPGA/DATA21: U8.V20 (IO_L11N_T1_SRCC_14); also elsewhere on the board
/FPGA/DATA22: U8.W22 (IO_L7N_T1_D10_14); also elsewhere on the board
/FPGA/DATA23: U8.W21 (IO_L7P_T1_D09_14); also elsewhere on the board
/FPGA/DATA24: U8.Y22 (IO_L9N_T1_DQS_D13_14); also elsewhere on the board
/FPGA/DATA25: U8.Y21 (IO_L9P_T1_DQS_14); also elsewhere on the board
/FPGA/DATA26: U8.AA21 (IO_L8N_T1_D12_14); also elsewhere on the board
/FPGA/DATA27: U8.AB22 (IO_L10N_T1_D15_14); also elsewhere on the board
/FPGA/DATA28: U8.AA20 (IO_L8P_T1_D11_14); also elsewhere on the board
/FPGA/DATA29: U8.AB21 (IO_L10P_T1_D14_14); also elsewhere on the board
/FPGA/DATA30: U8.AA19 (IO_L15P_T2_DQS_RDWR_B_14); also elsewhere on the board
/FPGA/DATA31: U8.AB20 (IO_L15N_T2_DQS_DOUT_CSO_B_14); also elsewhere on the board
GND: C59.2, C60.2, C61.2, C62.2, C63.2, C64.2, C65.2; also elsewhere on the board

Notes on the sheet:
Notes: ------------ TODO: Determine if EMCCLK is needed or the internal clock is fine for QSPI Arty A7 toes EMCCLK to CCLK_0 via 49.9 resistor ------------ UG470 Page 22 Table 2-4: Configuration Pin Definitions (Cont'd) Active-Low PUDC_B input enables internal pull-up resistors on the SelectIO pins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
R15
P18
T22
M14
Y20
U19

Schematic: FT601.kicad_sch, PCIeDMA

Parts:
C40, C41, C42, C43: 0.1u; C_0402_1005Metric; Rating 16V
C44: 4.7u; C_0603_1608Metric; Rating 16V
R24: 10k; R_0402_1005Metric; Rating 1/16W; Tolerance 1%
R25: 1.6k; R_0402_1005Metric; Rating 1/16W; Tolerance 1%
U7: FT601Q; QFN-76-1EP_9x9mm_P0.4mm_EP5.81x6.31mm
Y2: 30MHz; Crystal_SMD_3225-4Pin_3.2x2.5mm

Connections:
+5V_DATA: U7.37 (VBUS); also elsewhere on the board
+VCCO: C42.1, R24.1, U7.14 (VCCIO), U7.20 (VCC33), U7.24 (VCC33), U7.28 (VDDA), U7.38 (VCC33), U7.49 (VCCIO), U7.59 (VCCIO), U7.68 (VCCIO); also elsewhere on the board
/FPGA/BE0: U7.4 (BE_0); also elsewhere on the board
/FPGA/BE1: U7.5 (BE_1); also elsewhere on the board
/FPGA/BE2: U7.6 (BE_2); also elsewhere on the board
/FPGA/BE3: U7.7 (BE_3); also elsewhere on the board
/FPGA/CLK: U7.58 (CLK); also elsewhere on the board
/FPGA/DATA0: U7.40 (DATA_0); also elsewhere on the board
/FPGA/DATA1: U7.41 (DATA_1); also elsewhere on the board
/FPGA/DATA2: U7.42 (DATA_2); also elsewhere on the board
/FPGA/DATA3: U7.43 (DATA_3); also elsewhere on the board
/FPGA/DATA4: U7.44 (DATA_4); also elsewhere on the board
/FPGA/DATA5: U7.45 (DATA_5); also elsewhere on the board
/FPGA/DATA6: U7.46 (DATA_6); also elsewhere on the board
/FPGA/DATA7: U7.47 (DATA_7); also elsewhere on the board
/FPGA/DATA8: U7.50 (DATA_8); also elsewhere on the board
/FPGA/DATA9: U7.51 (DATA_9); also elsewhere on the board
/FPGA/DATA10: U7.52 (DATA_10); also elsewhere on the board
/FPGA/DATA11: U7.53 (DATA_11); also elsewhere on the board
/FPGA/DATA12: U7.54 (DATA_12); also elsewhere on the board
/FPGA/DATA13: U7.55 (DATA_13); also elsewhere on the board
/FPGA/DATA14: U7.56 (DATA_14); also elsewhere on the board
/FPGA/DATA15: U7.57 (DATA_15); also elsewhere on the board
/FPGA/DATA16: U7.60 (DATA_16); also elsewhere on the board
/FPGA/DATA17: U7.61 (DATA_17); also elsewhere on the board
/FPGA/DATA18: U7.62 (DATA_18); also elsewhere on the board
/FPGA/DATA19: U7.63 (DATA_19); also elsewhere on the board
/FPGA/DATA20: U7.64 (DATA_20); also elsewhere on the board
/FPGA/DATA21: U7.65 (DATA_21); also elsewhere on the board
/FPGA/DATA22: U7.66 (DATA_22); also elsewhere on the board
/FPGA/DATA23: U7.67 (DATA_23); also elsewhere on the board
/FPGA/DATA24: U7.69 (DATA_24); also elsewhere on the board
/FPGA/DATA25: U7.70 (DATA_25); also elsewhere on the board
/FPGA/DATA26: U7.71 (DATA_26); also elsewhere on the board
/FPGA/DATA27: U7.72 (DATA_27); also elsewhere on the board
/FPGA/DATA28: U7.73 (DATA_28); also elsewhere on the board
/FPGA/DATA29: U7.74 (DATA_29); also elsewhere on the board
/FPGA/DATA30: U7.75 (DATA_30); also elsewhere on the board
/FPGA/DATA31: U7.76 (DATA_31); also elsewhere on the board
/FPGA/OE: U7.13 (OE_N); also elsewhere on the board
/FPGA/RD: U7.12 (RD_N); also elsewhere on the board
/FPGA/RST: C43.1, R24.2, U7.15 (RESET_N); also elsewhere on the board
/FPGA/RXF: U7.9 (RXF_N); also elsewhere on the board
/FPGA/SIWU: U7.10 (SIWU_N); also elsewhere on the board
/FPGA/TXE: U7.8 (TXE_N); also elsewhere on the board
/FPGA/WAKEUP: U7.16 (WAKEUP_N); also elsewhere on the board
/FPGA/WR: U7.11 (WR_N); also elsewhere on the board
/USB Data/FT601/DM: U7.25 (DM); also elsewhere on the board
/USB Data/FT601/DP: U7.23 (DP); also elsewhere on the board
/USB Data/FT601/FT601_XI: C40.1, U7.17 (XI), Y2.1
/USB Data/FT601/FT601_XO: C41.1, U7.18 (XO), Y2.3
/USB Data/FT601/RIDN: U7.34 (RIDN); also elsewhere on the board
/USB Data/FT601/RIDP: U7.35 (RIDP); also elsewhere on the board
/USB Data/FT601/RREF: R25.1, U7.27 (RREF)
/USB Data/FT601/TODN: U7.31 (TODN); also elsewhere on the board
/USB Data/FT601/TODP: U7.32 (TODP); also elsewhere on the board
/USB Data/FT601/VD10: C44.1, U7.2 (AVDD), U7.3 (VD10), U7.30 (VD10), U7.33 (VD10), U7.39 (DV10), U7.48 (VD10)
GND: C40.2, C41.2, C42.2, C43.2, C44.2, R25.2, U7.1 (GND), U7.26 (GND), U7.29 (GND), U7.36 (GND), U7.77 (EP), Y2.2, Y2.4; also elsewhere on the board

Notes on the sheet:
AC coupling caps on mux sheet

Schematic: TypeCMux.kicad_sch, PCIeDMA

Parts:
C31, C32, C33, C34, C35, C36, C37, C39: 0.1u; C_0402_1005Metric; Rating 16V
C38: 0.47u; C_0402_1005Metric; Rating 10V
Q1: Q_NMOS_DGS; SOT-23
R19: 900k; R_1206_3216Metric; Rating 0.1W; Tolerance 1%
R20: 200k; R_0402_1005Metric; Rating 1/16W; Tolerance 1%
R21, R22, R23: 10k; R_0402_1005Metric; Rating 1/16W; Tolerance 1%
U6: HD3SS3220

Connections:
+5V_DATA: C35.1, R19.1, R22.2, R23.1, U6.30 (VDD5); also elsewhere on the board
+VCCO: C36.1, R20.1, R21.1, U6.8 (VCC33); also elsewhere on the board
/USB Data/FT601/RIDN: U6.10 (RXn); also elsewhere on the board
/USB Data/FT601/RIDP: U6.9 (RXp); also elsewhere on the board
/USB Data/FT601/TODN: C37.2; also elsewhere on the board
/USB Data/FT601/TODP: C39.2; also elsewhere on the board
/USB Data/Type C Mux/CC1: U6.2 (CC1); also elsewhere on the board
/USB Data/Type C Mux/CC2: U6.1 (CC2); also elsewhere on the board
/USB Data/Type C Mux/DIR: R20.2, U6.11 (DIR)
/USB Data/Type C Mux/ENn: Q1.1 (D), R21.2, U6.12 (ENn_MUX), U6.29 (ENn_CC)
/USB Data/Type C Mux/ENn_G: C38.1, Q1.2 (G), R22.1
/USB Data/Type C Mux/RX1n: U6.14 (RX1n); also elsewhere on the board
/USB Data/Type C Mux/RX1p: U6.15 (RX1p); also elsewhere on the board
/USB Data/Type C Mux/RX2n: U6.18 (RX2n); also elsewhere on the board
/USB Data/Type C Mux/RX2p: U6.19 (RX2p); also elsewhere on the board
/USB Data/Type C Mux/TOD_C_n: C37.1, U6.7 (TXn)
/USB Data/Type C Mux/TOD_C_p: C39.1, U6.6 (TXp)
/USB Data/Type C Mux/TX1_C_n: C33.2, U6.16 (TX1n)
/USB Data/Type C Mux/TX1_C_p: C31.2, U6.17 (TX1p)
/USB Data/Type C Mux/TX1n: C31.1; also elsewhere on the board
/USB Data/Type C Mux/TX1p: C33.1; also elsewhere on the board
/USB Data/Type C Mux/TX2_C_n: C34.2, U6.20 (TX2n)
/USB Data/Type C Mux/TX2_C_p: C32.2, U6.21 (TX2p)
/USB Data/Type C Mux/TX2n: C32.1; also elsewhere on the board
/USB Data/Type C Mux/TX2p: C34.1; also elsewhere on the board
/USB Data/Type C Mux/VBUS_DET: R19.2, U6.5 (VBUS_DET)
GND: C35.2, C36.2, C38.2, Q1.3 (S), R23.2, U6.4 (PORT), U6.13 (GND), U6.28 (GND), U6.31 (EP); also elsewhere on the board

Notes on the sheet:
HD3SS3220 Does Not Care About Differential Pair Polarity
NC = GPIO mode
Ingored in UFP
Requires 200k pu
Don't care in UFP
Notes: ------------ 7.3.12 VDD5 and VCC33 Power-On Requirements The HD3SS3220 has two power supplies: VDD5 and VCC33. The VDD5 supply powers the internal CC controller and also provides VCONN to either CC1 or CC2. The VCC33 powers the 2:1 MUX. The HD3SS3220 non-failsafe pins are the following: PORT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
Notes: ------------ Schematic based on datasheet 8.2.4 UFP port
Port low = UFP mode UFP mode is pulldowns on both CC pins

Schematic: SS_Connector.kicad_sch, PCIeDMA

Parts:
C30: 10u; C_0603_1608Metric; Rating 25V
FB2: TBD; L_0805_2012Metric
J4: USB_C_Receptacle; USB_C_Receptacle_Molex_105450-0101
U3, U4, U5: TPD4EUSB30; USON-10_2.5x1.0mm_P0.5mm

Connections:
+5V_DATA: C30.1, FB2.2; also elsewhere on the board
/USB Data/FT601/DM: J4.A7 (D-), J4.B7 (D-), U3.5 (D2-), U3.6 (NC); also elsewhere on the board
/USB Data/FT601/DP: J4.A6 (D+), J4.B6 (D+), U3.4 (D2+), U3.7 (NC); also elsewhere on the board
/USB Data/Type C Mux/CC1: J4.A5 (CC1), U3.1 (D1+), U3.10 (NC); also elsewhere on the board
/USB Data/Type C Mux/CC2: J4.B5 (CC2), U3.2 (D1-), U3.9 (NC); also elsewhere on the board
/USB Data/Type C Mux/RX1n: J4.B10 (RX1-), U4.1 (D1+), U4.10 (NC); also elsewhere on the board
/USB Data/Type C Mux/RX1p: J4.B11 (RX1+), U4.2 (D1-), U4.9 (NC); also elsewhere on the board
/USB Data/Type C Mux/RX2n: J4.A10 (RX2-), U5.1 (D1+), U5.10 (NC); also elsewhere on the board
/USB Data/Type C Mux/RX2p: J4.A11 (RX2+), U5.2 (D1-), U5.9 (NC); also elsewhere on the board
/USB Data/Type C Mux/TX1n: J4.A3 (TX1-), U4.5 (D2-), U4.6 (NC); also elsewhere on the board
/USB Data/Type C Mux/TX1p: J4.A2 (TX1+), U4.4 (D2+), U4.7 (NC); also elsewhere on the board
/USB Data/Type C Mux/TX2n: J4.B3 (TX2-), U5.5 (D2-), U5.6 (NC); also elsewhere on the board
/USB Data/Type C Mux/TX2p: J4.B2 (TX2+), U5.4 (D2+), U5.7 (NC); also elsewhere on the board
/USB Data/Type C SS Connector/VBUS_DATA: FB2.1, J4.A4 (VBUS), J4.A9 (VBUS), J4.B4 (VBUS), J4.B9 (VBUS)
GND: C30.2, J4.A1 (GND), J4.A12 (GND), J4.B1 (GND), J4.B12 (GND), J4.S1 (SHIELD), U3.3 (GND), U3.8 (GND), U4.3 (GND), U4.8 (GND), U5.3 (GND), U5.8 (GND); also elsewhere on the board

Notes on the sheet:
Notes: ------------ +5V_Data is used for the mux and FT601 ------------ TPD4EUSB30 is used instead of a single part to simplify the BOM, as this can be used for the jtag interface too.

Board: 8 copper layers, 235 parts (99 on the bottom side), 207 nets, no tracks yet.

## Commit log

2023-02-20 Routing and layout, first pass
    [FPGA_Bank0.kicad_sch, FPGA_Bank13-14.kicad_sch, FPGA_Bank15-16.kicad_sch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]
2024-01-01 Second pass
    [BOM-PCIeDMA.csv, FPGA.kicad_sch, FPGA_Bank0.kicad_sch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]
2024-01-08 Third pass
    [BOM-PCIeDMA.csv, FPGA.kicad_sch, FPGA_Bank0.kicad_sch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]
2024-03-11 another quick pass
    [1054500101.stp, BOM-PCIeDMA.csv, FPGA.kicad_sch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]
